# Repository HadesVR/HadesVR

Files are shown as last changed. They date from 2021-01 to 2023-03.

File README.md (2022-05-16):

EN
ES

name

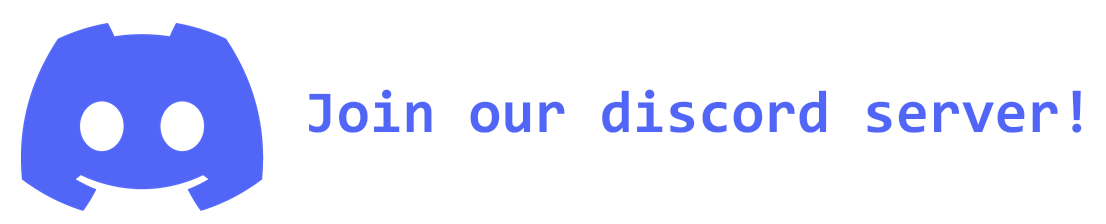
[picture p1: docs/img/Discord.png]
Discord (https://discord.gg/h2SFGEbuRH)

I made a discord server for support and whatever so [feel free to join.](https://discord.gg/h2SFGEbuRH)

# HadesVR       
HadesVR is a SteamVR compatible VR setup made for tinkerers. 

The setup includes DIY controllers that are capable of emulating HTC vive wands or most aspects of the Valve Index Knuckles controllers (including finger tracking!). It also includes tracking electronics for a Headset, including an integrated wireless receiver to receive the controllers' data.

There's also custom controller hardware like 3d printable shells (still a bit of a WIP) with their respective custom PCBs to build your own Knuckles controllers.

The SteamVR driver used to be based off of [TrueOpenVR](https://github.com/TrueOpenVR) but it's modified so heavily I'm making it it's own thing.
This driver also uses [PSMoveServiceEX](https://github.com/Timocop/PSMoveServiceEx) (for now at least) for the positional tracking of HMD and controllers, using ping pong balls and different colours of LED's.

For more information on *everything*, check out the [docs](docs/DocsIndex.md)!

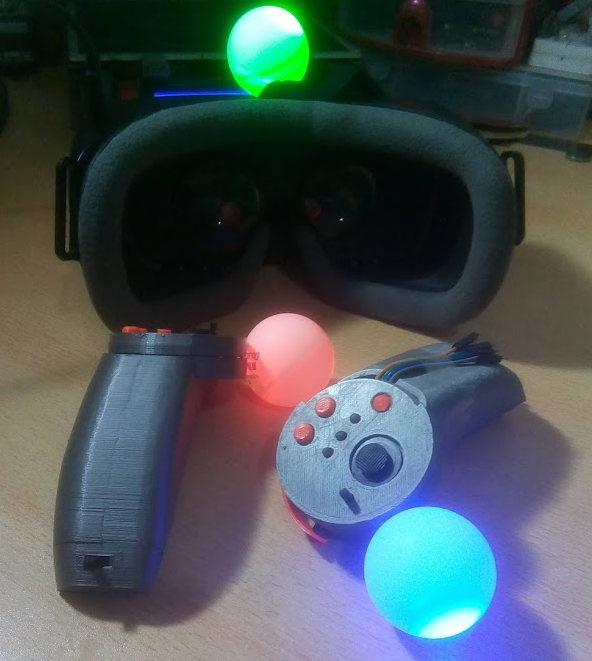
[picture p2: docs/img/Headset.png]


# How does it work and what can it do?

The headset connects to the PC and receives rotation and button data from both controllers through RF, while the tracking is done outside-in (base stations) using Playstation Move Cameras and [PSMoveService](https://github.com/psmoveservice/PSMoveService).

You can use the setup in: 
* Headset and controllers mode: The headset receives data from the controlers and mixed with the PSMoveService position tracking you get full 6dof tracking.
* Headset only mode: where you only have your HadesVR headset and the 6dof tracking (or 3dof if you don't use PSMoveService)
* Controller only mode: where if you already have a headset, you can use only the controllers part of the setup (you'll need to build an [RF receiver](docs/RFReceiver.md) to replace the HadesVR headset's built in one).

## What it can and cannot do:
* This driver can emulate Wand and Index controllers.
* This setup cannot do Inside out tracking.
* This driver cannot do Full body tracking ~~**yet**~~.
* Yes this thing plays beatsaber though I'm not sure how viable it is for expert+ diff since I suck at it.

# Custom hardware

As of right now the custom hardware available is:

### ⚠️Both the Basic HMD and Wand Controllers are missing the 3d printable parts right now. 
* [HadesVR Basic HMD PCB](https://github.com/HadesVR/Basic-HMD-PCB) 
* [HadesVR Wand Controllers](https://github.com/HadesVR/Wand-Controller)

### ⚠️Important disclaimer: I **very** very heavily discourage against building the knuckles controller, it's got a whole lot of problems right now that I haven't gotten around to fixing yet, there's problems with the boards and there's problems with the 3d printer models, and there's problems with the reliability of the capacitive sensors of each finger. The index controller is not an easy build: it relies on a lot of SMD components, stuff has to be assambled in order or else you won't be able to flash the bootloader and the 3d printable parts are all a bit crappy and hard to fit together properly. 

### Also there is a bit of an issue with the boards right now which makes it hard to flash the bootloader since AVR's require a crystal to do that for some dumb reason, so I heavily recommend against making the custom Index controllers for now.

#### I'm also working on an easier to build type of controllers that emulate the vive wands, made only out of through hole components though it's not ready yet (mainly missing the 3d printable shell at the moment). With that being said:

Or maybe you want to DIY your own controllers? check out the [Controllers docs](docs/DocsIndex.md#controllers) for building the controllers with regular Arduino boards!

# Demos

I've recorded a few demos of my HadesVR setup working in different games, these are all available in this [Youtube Playlist](https://www.youtube.com/playlist?list=PLPNX9YMrhQR2g2nwp1AN23K4V-8d-4bBV)

# Trello
I used to have a crappy little TODO list here but I'm gonna try to use [trello for HadesVR work](https://trello.com/b/4Ogw6SMk/hadesvr-stuff)

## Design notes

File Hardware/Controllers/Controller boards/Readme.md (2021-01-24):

# Controller boards

You can get the board files and stuff over [Here][BoardLink]

If you're using the custom controller boards, you'll have something that looks like this in your hands

Boards

You'll have to snap them off so you're left with two pairs of controller boards and a blank pcb square.

[BoardLink]: <https://oshwlab.com/liquidcgs/vrcontrollers_public>

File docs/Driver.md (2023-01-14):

# Driver

# Driver Installation
Driver installation is quite simple, the steps are as follows:
* Download the latest release of the driver from the [Releases Page](https://github.com/HadesVR/HadesVR/releases)
* Unzip the driver into your Steam\steamapps\common\SteamVR\drivers folder.
* Configure the driver

Assuming you have already followed the steps in the [Tracking](Tracking.md) doc, you should have PSMoveService already installed in your PC.

If you don't plan on making a 6dof headset (a 3dof headset for Sim racing, etc), you can skip the PSMoveService related steps.

# Driver Configuration

Driver configuration is pretty self explanatory, the driver configuration file is stored in hadesvr\resources\settings\default.vrsettings. To change the settings just open the file with the text editor of your liking.

If you're planning to use different drivers at the same time (HadesVR controllers with TOVR HMD for example), you'll also need to enable the `activateMultipleDrivers` setting in the Steam\config\steamvr.vrsettings file. 

The driver configuration is divided into a couple sections for tidyness, these are the following:

### "Driver" section where you'll find:
|Parameter|Type |Description|
| ---  | --- |--- |
| TransportMode | string | Either HID or UART depending on how HMD is connected, see below. |
| PSMSTrackerFrequency | int | The maximum update rate you have set on your psmoveservice trackers.|
| EnableDirectMode | bool | Enable direct mode? (Experimental, sort of broken. default value is 'false'.|
| EDID_VID | int | EDID VID for direct mode.|
| EDID_PID | int | EDID PID for direct mode.|

If `TransportMode` is set to `HID` (or left unset):

|Parameter|Type |Description|
| ---  | --- |--- |
| HID_VID | int | The VID value of your HID device, in decimal numbers. |
| HID_PID | int | The PID value of your HID device, in decimal numbers. |

If `TransportMode` is set to `UART`:

|Parameter|Type |Description|
| ---  | --- |--- |
| UART_Port | string | UART port name HMD is connected to, e.g. COM3. |
| UART_Baudrate | int | Baudrate used for UART communication, e.g. 115200 or 230400. |

### "Display" section where you'll find:
|Parameter|Type |Description|
| ---  | --- |--- |
| Stereo  | bool | Enables or disables Stereo display mode, keep enabled unless you're a cyclops. |
| IsDisplayOnDesktop  | bool | This makes it so a warning telling you your display isn't in fullscreen mode pops up when your window focus isn't on the VR viewport. |
| IsDisplayReal  | bool | ------ |
| IsSinglePanel  | bool | Set to true if using a single panel display. |
| IPD  | float | IPD setting, in meters. |
| FOV  | float | FOV setting, in degrees. |
| windowWidth  | int | Resolution Width of your VR screen |
| windowHeight  | int | Resolution Height of your VR screen |
| renderWidth  | int | The width (per eye) of the desired render resolution. |
| renderHeight  | int |The height (per eye) of the desired render resolution. |
| displayFrequency  | float | Here goes the refresh rate of your display. |
| windowX  | int | Here goes the Width resolution of your main screen. |
| windowY  | int | Don't touch this one. |
| ScreenOffsetX  | int | Viewport X offset. |
| ScreenOffsetY  | int | Viewport Y offset. |
| ViewportZoom  | float | Viewport Zoom, lower means higher zoom. |
| DistanceBetweenLenses  | float | This is the physical distance between the two lenses, in meters |
| DistanceBetweenViews  | float | Distance between views, in meters. This should be set as same as IPD in single panel mode and 0 in dual panel mode. |
| DisplayWidth  | float | Physical width of the display, in meters |
| DisplayCantAngle  | float | Cant angle in degrees of the displays (Experimental, slightly broken, things don't render properly at the edges of the views). |
| secondsFromVsyncToPhotons  | float | ------ |

### "Distortion" section where you'll find:
|Parameter|Type |Description|
| ---  | --- |--- |
| Red_K1,K2,K3  | float | Red distortion coefficients |
| Green_K1,K2,K3  | float | Green distortion coefficients|
| Blue_K1,K2,K3 |float| Blue distortion coefficients |

### "HMD" section where you'll find:
|Parameter|Type |Description|
| ---  | --- |--- |
| serialNumber  | string | The serial number of the HMD |
| modelNumber  | string | The model of the HMD |
| EnableHMD  | bool | Enables or disables the HMD part of the driver |
| MinFilterBeta | float | Minimum filter beta of the rotation filter |
| MaxFilterBeta | float | Maximum filter beta of the rotation filter |
| UseAccelerometers | bool | Enables the use of the IMU's accelerometer for position smoothing |
| Camera_Kalman_Measurement_Uncertainty | float | Camera measurement uncertainty of the Kalman position filter |
| Camera_Kalman_Estimation_Uncertainty | float | Camera estimation uncertainty of the Kalman position filter |
| Camera_Kalman_Process_Noise | float | Camera process noise of the Kalman position filter |
| IMU_Kalman_Measurement_Uncertainty | float | IMU measurement uncertainty of the Kalman position filter |
| IMU_Kalman_Estimation_Uncertainty | float | IMU estimation uncertainty of the Kalman position filter |
| IMU_Kalman_Process_Noise | float | IMU process noise of the Kalman position filter |
|HMDYawOffset|float| Yaw offset of the HMD in degrees|
|HMDPitchOffset|float| Pitch offset of the HMD in degrees|
|HMDRollOffset|float| Roll offset of the HMD in degres|
|HMDXOffset|float| X offset of the HMD in meters|
|HMDYOffset|float| Y offset of the HMD in meters|
|HMDZOffset|float| Z offset of the HMD in meters|

### "Controllers" section where you'll find:
|Parameter|Type |Description|
| ---  | --- |--- |
| EnableControllers  | bool | Variable to enable or disable controllers. |
| ControllerMode  | int | Sets the controller type, 0 being Knuckles controllers and 1 being wand controllers. |
| UseAccelerometers | bool | Enables the use of the IMU's accelerometer for position smoothing |
| Camera_Kalman_Measurement_Uncertainty | float | Camera measurement uncertainty of the Kalman position filter |
| Camera_Kalman_Estimation_Uncertainty | float | Camera estimation uncertainty of the Kalman position filter |
| Camera_Kalman_Process_Noise | float | Camera process noise of the Kalman position filter |
| IMU_Kalman_Measurement_Uncertainty | float | IMU measurement uncertainty of the Kalman position filter |
| IMU_Kalman_Estimation_Uncertainty | float | IMU estimation uncertainty of the Kalman position filter |
| IMU_Kalman_Process_Noise | float | IMU process noise of the Kalman position filter |
|CTRLRightYawOffset | float | Yaw offset of the Right controller in degrees|
|CTRLRightPitchOffset | float | Pitch offset of the Right controller in degrees|
|CTRLRightRollOffset | float | Roll offset of the Right controller in degrees|
|CTRLRightXOffset|float| X offset of the Right controller in meters|
|CTRLRightYOffset|float| Y offset of the Right controller in meters|
|CTRLRightZOffset|float| Z offset of the Right controller in meters|
|CTRLLeftYawOffset | float | Yaw offset of the Left controller in degrees|
|CTRLLeftPitchOffset | float | Pitch offset of the Left controller in degrees|
|CTRLLeftRollOffset | float | Roll offset of the Left controller in degrees|
|CTRLLeftXOffset|float| X offset of the Left controller in meters|
|CTRLLeftYOffset|float| Y offset of the Left controller in meters|
|CTRLLeftZOffset|float| Z offset of the Left controller in meters|

### "Trackers" section where you'll find:
|Parameter|Type |Description|
| ---  | --- |--- |
|EnableTrackers| bool| Enables or disables trackers (still work in progress, trackers do nothing as of right now.)
|TrackerMode| int | 0 meaning full body, 1 meaning waist tracking. |

### "Experimental" section where you'll find:
|Parameter|Type |Description|
| ---  | --- |--- |
|EnableDriftCorrection| bool| Enables or disables experimental drift correction
|LowerVelocityTreshold| float | The lower threshold of velocity in m/s in which the driver will attempt to correct for drift |
|UpperVelocityTreshold| float | The upper threshold of velocity in m/s in which the driver will attempt to correct for drift |
|Measurement_Uncertainty| float | Kalman filter measurement uncertainty for the smoothing filter used in drift correction. |
|Estimation_Uncertainty| float | Kalman filter estimation uncertainty for the smoothing filter used in drift correction. |
|HMD_Process_Noise| float | Kalman filter process noise for the smoothing filter used in drift correction on the HMD. 0 disables it |
|Controller_Process_Noise| float | Kalman filter process noise for the smoothing filter used in drift correction on the Controllers. 0 disables it |

# HID configuration
To configure the driver you will need the VID and PID values from the board you're using. The easiest way of getting them is going to the Arduino IDE, clicking on tools and clicking on get board info with the receiver plugged in:

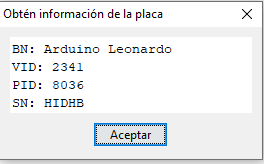
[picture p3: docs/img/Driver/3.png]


Do note these values are in HEX so to use them in the driver config file you'll need to convert them to decimal numbers.
to do that you can use websites like [Rapidtables](https://www.rapidtables.com/convert/number/hex-to-decimal.html), just input your VID and PID values one at a time and convert them to decimal numbers.

Once done, you'll get values like these and then all you have to do is load them up in your driver config file, the values you're looking to change are `HID_VID` and `HID_PID`, under the `Driver` section.



Make sure not to delete any commas, and not to get the VID and PID values backwards and proceed with the Display configuration.

# Display configuration

for your headset display to be recognized properly you must align it flat with the top right corner of your main display as seen in the following example:

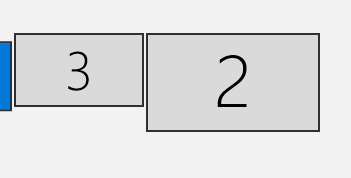
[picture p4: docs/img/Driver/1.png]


3 being your main display and 2 being your HMD's display. then you must input the Width of your main display (3 in this case) in pixels onto the `windowX` setting on the settings file but do not modify the windowY value of 0.

Then you've gotta set `windowWidth` and `windowHeight` to the respective width and height values of your vr screen, same goes for `renderWidth` and `renderHeight`. And last but not least: Set the `displayFrequency` to the one of your HMD's display.

If this doesn't work you might have messed up the alignment of the displays on the screen settings, remember the top line has to be flat like in the example picture.

you can also show the main vr output on your main screen for testing purposes by doing the following:
- Set `windowWidth` and `windowHeight` to the width and height of your main display
- Set the `renderWidth` and `renderHeight` to the width and height of your main display
- Set `windowX` to 0

# Usage and controller bindings

* Launch PSMoveService before opening SteamVR
* Launch SteamVR
* Close the "Running on monitor mode" notice
* Click on the Screen Viewport
* Calibrate controllers and headset by pressing F8 on your keyboard or the respective binding for it. (more on calibration below)

⚠️ if you just turned on your controllers/hmd it might drift for up to a minute, this is normal and you just need to keep it stil for a couple seconds until it settles.

## Initial calibration:
[TODO]
 
## Bindings:
### HMD only bindings:
Pressing F8 resets your yaw axis in case of IMU drift.

### Knuckles and Wand controllers:
Pressing Joystick click + trigger button on both controllers at the same time resets the yaw axis, make sure you're facing the correct way before doing so or else your controllers' axis will not match your headset axis.

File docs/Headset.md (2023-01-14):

# Headset
The headset will not only be in charge of showing you the image and relaying back rotation data from it's internal IMU, but it will also be in charge of receiving the RF Controller data and sending it back to the computer. Another thing that can be integrated into the headset is an USB Sound Card, that way it'll also have an integrated Microphone and a headphone jack for you to plug your headphones in. Though it's not mandatory.

I plan on eventually making a custom pcb for the headset that includes a 2 port USB hub, an audio interface for headphones and microphone integration, and maybe a couple other goodies like an attempt at backlight strobing to reduce screen blur.

# Hardware Needed

## Shell
For the shell you can use any "Phone VR" enclosure, they come in very different qualities but all of them should do the trick (even the carboard ones). Keep in mind the enclosure will dictate your max fov and that you can always modify the shell to allow for a wider fov.

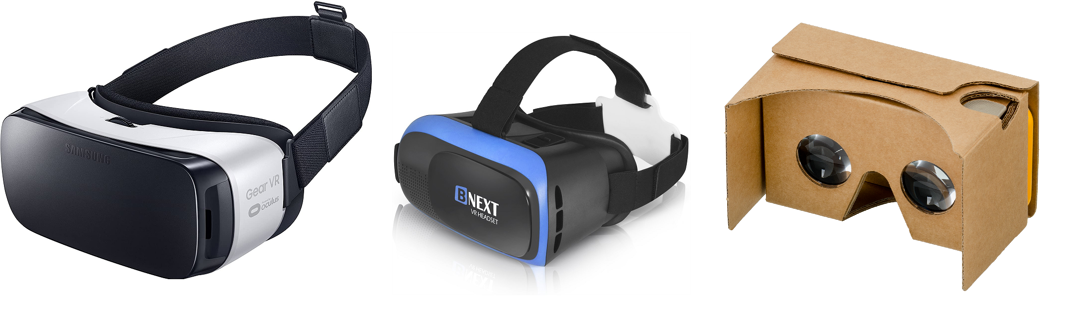
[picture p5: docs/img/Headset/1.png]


You could also 3d print the shell, like the guys over at [Relativty](https://github.com/relativty/Relativty#building-the-mechanical-parts) did. Keep in mind you'll also need to source your own lenses with the correct focal length and head strap.

⚠️ The screen mount depends on what screen you use and you'll have to design your own sice not all mounts fit all headsets/screen combinations.

## Electronics

As the main microcontroller I suggest sticking to stuff that supports the [Arduino HID library](https://www.arduino.cc/en/Reference/HID). That means:

* Arduino Leonardo
* Arduino Pro micro
* Arduino DUE (code might require some modification since it doesn't support EEPROM.)

An ideal candidate is the Arduino Pro Micro since it's based on the Atmega32u4 which is the microcontroller used on the Arduino Leonardo and it's fairly small.

Also needed are:
* An MPU9250 to gather rotation data (though you could use any IMU that's fast enough and can output rotation data to quaternions if you modify the code a bit to allow for that).

* An NRF24L01 to receive the controller data from both controllers*

* A 5v to 3.3v voltage regulator to power the NRF24 module*

* A High brightness LED that's a different colour from the ones used on the controllers (I suggest green) and a resistor for that LED for blob tracking (also needed is a white ping pong ball to put the LED into)**

    *: Only needed if you're also building the controllers.
    **: Only needed for 6dof tracking.

## Display(s)

There's a couple different displays you can use for this headset, anything from 4.5 to 6 inches should work just fine.
*As of right now*, using a phone with ALVR or RiftCat or whatever isn't supported though.

You can find these screens on Aliexpress, but make sure what you're getting is what you think you're getting. Ask the seller if the screen **AND** the driver board support the resolution and refresh rate they advertise.

Most of these screens come with a Blue driver board based around the [Toshiba TC358870XBG](https://toshiba.semicon-storage.com/ap-en/semiconductor/product/interface-bridge-ics-for-mobile-peripheral-devices/hdmir-interface-bridge-ics/detail.TC358870XBG.html), be skeptical of these boards since they support a huge multitude of displays at different refresh rates and resolutions, some sellers even claim they can drive two displays at 90hz.

There's a couple different versions of these blue driver boards, the most common one based around the TOSHIBA chip, the other one based on a clone of said chip.

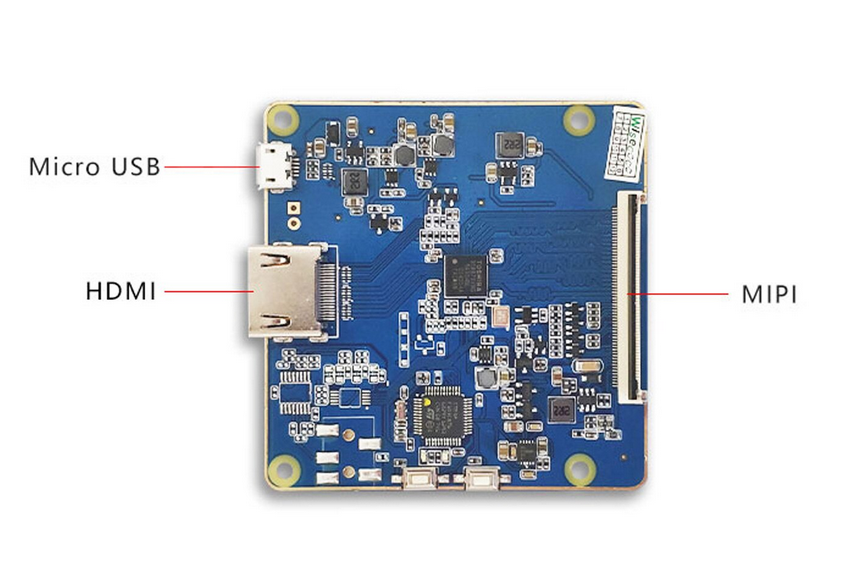
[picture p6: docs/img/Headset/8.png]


Some screen options are:

### LS055R1SX04 with Green board
With this option you'll have to purchase the [display](https://www.aliexpress.com/item/4000999801804.html) and [board](https://www.aliexpress.com/item/1005002330323719.html) separately. Make sure you choose the right display to go with the right board (LS055R1SX04 lcd won't work with LS055R1SX03 board) and make sure the display has a backlight before purchasing since these are usually used for resin 3d printers.

These screens are 1440x2560(vertical), they officially support up to 60Hz but with the board linked below they can be pushed to around 72hz without artifacts.

The board is meant to run the display at 60hz but it can easily do 72hz if you create a custom resolution in nvidia control panel or amd's driver settings thing.

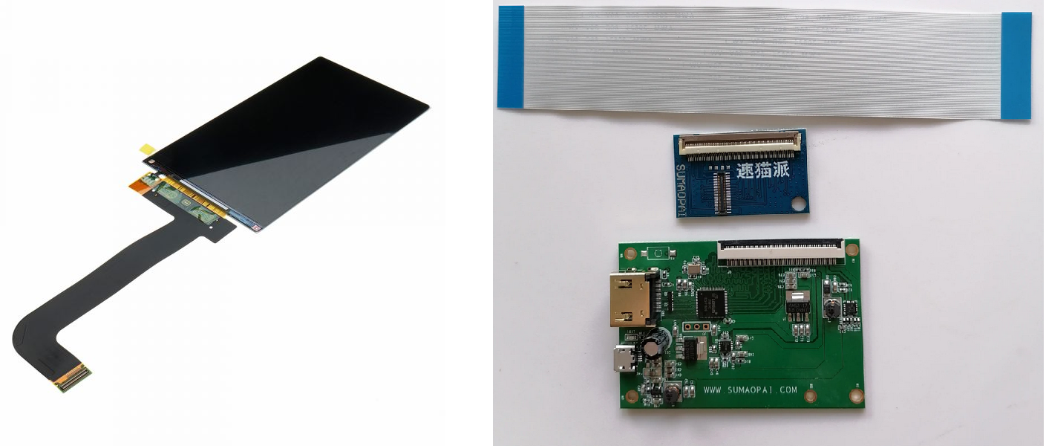
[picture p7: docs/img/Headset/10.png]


### LS055R1SX04 or LS055R1SX03 Blue board
These screens are 1440x2560(vertical), they officially support up to 60Hz but depending on the driver board they can be pushed to around 65hz without artifacts (this depends on the driver board).

⚠️ Make sure you're getting the correct refresh rate since a lot of sellers sell these boards with a driver board that's programmed to run at only 50hz

These are reasonably cheap since they're commonly used in resin 3d printers and can be found for around 50USD.

You can find these boards by searching with the terms "5.5 LCD MIPI"

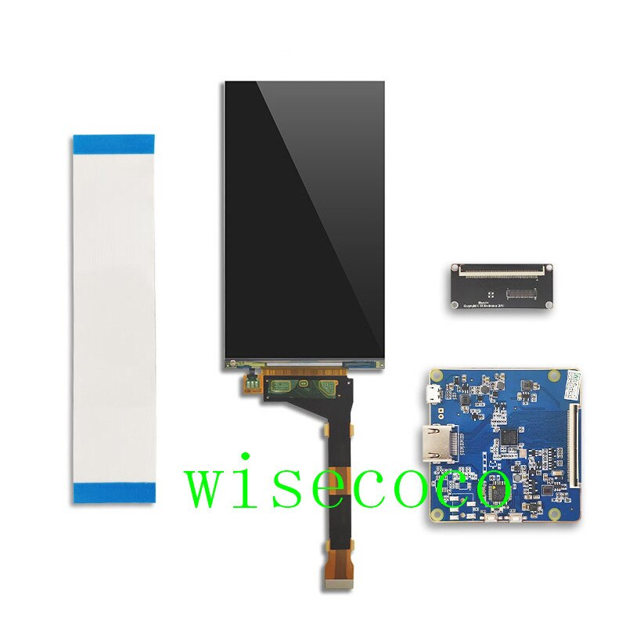
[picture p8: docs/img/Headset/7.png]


### Dual AMOLED H381DLN01
These screens are 1080x1200 per eye (2160x1200) and they claim to run at 90Hz.
They use the Blue driver board and the screens are 3.81 inches each and use AMOLED displays.

⚠️ Make sure you're getting the correct refresh rate before buying

⚠️ Make sure the driver splits the image into the two displays and doesn't just display the same image across both displays before buying.

These are a lot more expensive than the last one and can be found for around 170USD for the pair of screens + driver board
You can find these boards by searching with the terms "90Hz VR LCD"

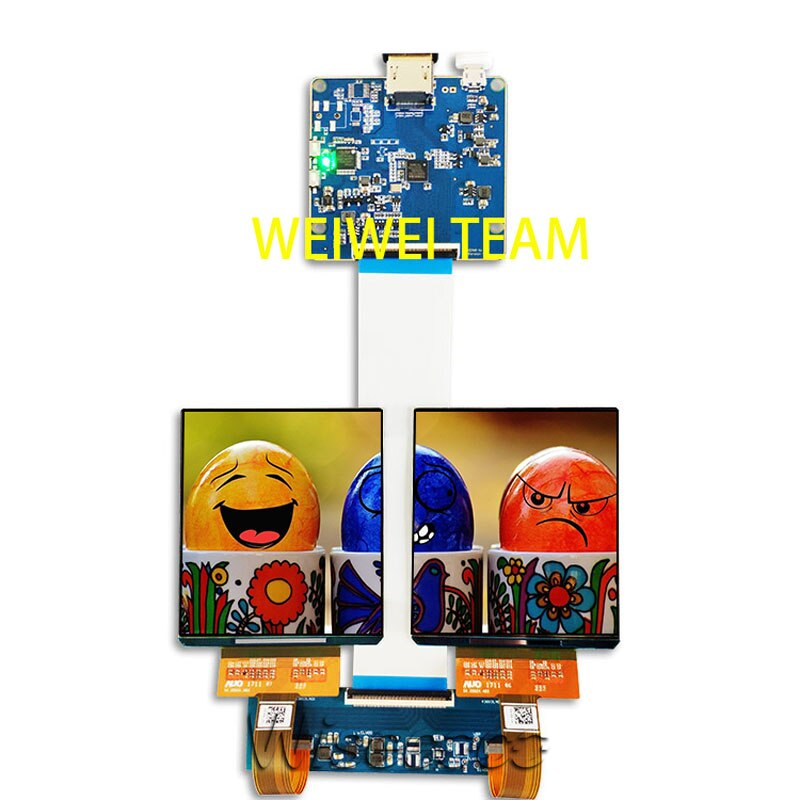
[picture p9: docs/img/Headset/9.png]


### Dual LS029B3SX02
These screens are 1440x1440 per eye (2880x1440) and run at 120hz.
The use a different driver board that uses DisplayPort as a video input and the displays are 2.9 inch IPS LCD.

⚠️ Make sure you're getting the correct refresh rate before buying

These go for around 180USD for the pair of screens and driver board, making them a better purchase than the dual AMOLED if you're looking for high refresh rate.

You can find these boards by searching with the terms "120Hz VR LCD"

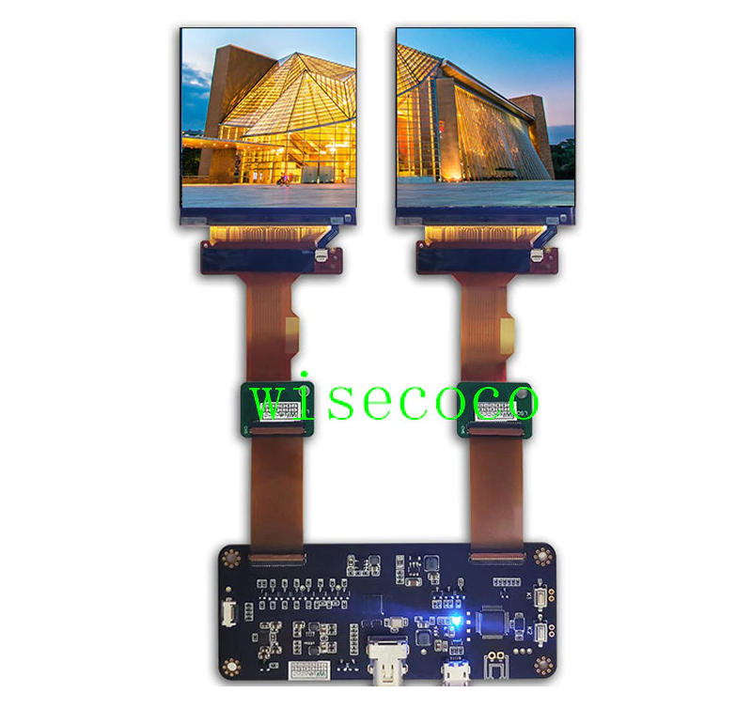
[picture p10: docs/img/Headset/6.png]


# Circuit schematic
Circuit pins for the Arduino pro micro are as follows:

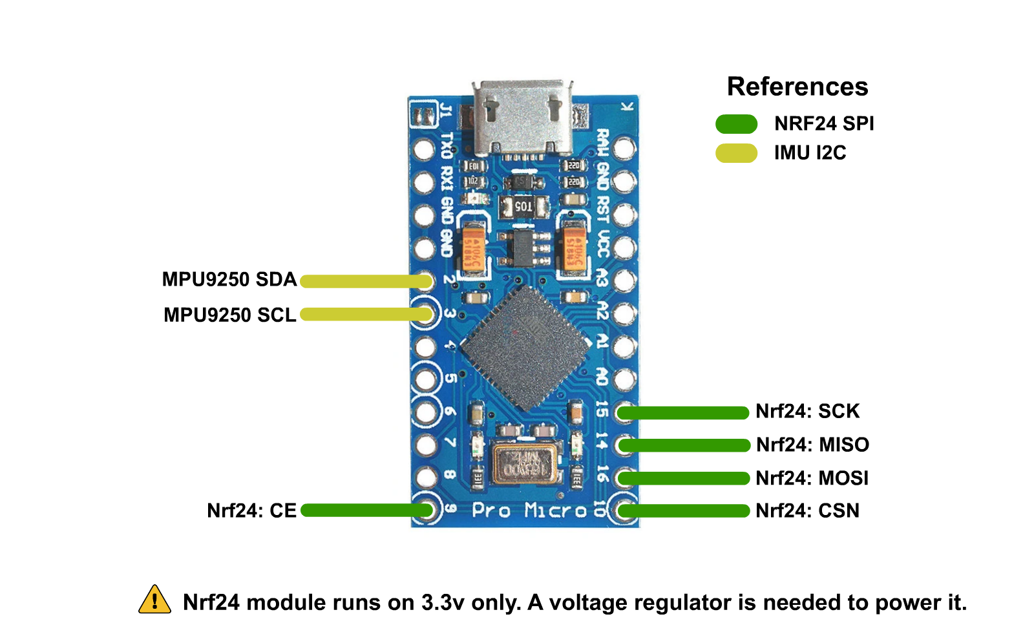
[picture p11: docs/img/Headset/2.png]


## ⚠️ IMPORTANT: YOU NEED A 5V TO 3.3V REGULATOR TO POWER THE NRF24 MODULE, ***THE PRO MICRO DOES NOT SUPPLY 3.3V ON ANY OF ITS PINS*** 
# Uploading the firmware

To upload the firmware you will need to have the [FastIMU](https://github.com/LiquidCGS/FastIMU) (also available on the Arduino library manager) and the [RF24 Arduino Library](https://github.com/nRF24/RF24) installed in your [Arduino IDE](https://www.arduino.cc/en/software). 

You can download the required library using the Libraries manager from within the Arduino IDE. The rest of the used libaries are already included in the firmware folder.

The steps to upload the firmware are as follows:

* Open Headset.ino inside the Software/Firmware/Headset folder
* Select "Arduino Leonardo" as the board if you're using an Arduino Pro Micro
* Select the correct COM port for the board
* Press the Upload button, if all goes well, you can move to setting the correct COMPort.

# Getting HID values

To configure the driver you will need the VID and PID values from the board you're using. The easiest way of getting them is going to the Arduino IDE, clicking on tools and clicking on get board info with the HMD plugged in:



Do note these values are in HEX so to use them in the driver config file you'll need to convert them to decimal numbers.
to do that you can use websites like [Rapidtables](https://www.rapidtables.com/convert/number/hex-to-decimal.html), just input your VID and PID values one at a time and convert them to decimal numbers.

Once done, you'll get values like these and then all you have to do is load them up in your driver config file. For more details on driver configuration, check out the [driver configuration docs](Driver.md#driver-configuration)



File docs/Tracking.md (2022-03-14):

# Tracking
The tracking of both controllers and the HMD is based on the same principle Playstation Move controllers are tracked. That is, by using different coloured blobs, and a camera (or multiple cameras) to know where in space each blob is located.

This type of tracking has the advantage of being reasonably cheap, since the blobs can be made out of ping pong balls and common LED's, and the cameras are standard Playstation Eye cameras.

## Why Playstation Eye cameras and not regular webcams?
- Playstation cameras can do up to 60fps at 640x480 which allows for smoother tracking.
- They are low cost and readily available.
- They have known lens distortion values. 
- All Playstation Eye cameras are created equal, which means a camera bought in the America and a camera bought in Europe will run exactly the same.

# What you'll need
- [Zadig](https://zadig.akeo.ie/)
- [PSMoveServiceEx](https://github.com/Timocop/PSMoveServiceEx)
- [PSMS Calibration mat](https://github.com/psmoveservice/PSMoveService/blob/master/misc/calibration/CalibrationMat.pdf), Ideally printed on letter paper, though A4 works fine too.
- *At least* 2 Playstation Eye cameras (**NOT** EYE TOY).
- USB extensions: you can extend up to 1.8m (6ft) (for a total of 3.6m (12ft)) with passive cables.

⚠️️ if you need more length you **will** have to use active cables.

## Why a *minimum* of 2 cameras and the amount I recommend.
A single camera results in jittery tracking since you can't do triangulation on a single camera and no redundancy, meaning that the second your tracking blob gets occluded (be it by your body or by something else) you'll lose all tracking.

Two cameras allow for triangulation and, *to some extent* redundancy. This is the bare minimum I'd recommend for vr.

The problem is that the moment one of your blobs gets occluded your tracking will turn into a jittery mess. *This is why I recommend three or four cameras.*

Three cameras not only allows for smoother, more accurate tracking, but it also allows for redundancy and since you only need two cameras for triangulation you can block the tracking blob for one camera entirely and still have decent tracking.

More cameras would allow for more redundancy, you can hook up as many as you want, but keep in mind USB bandwith limitations and processing power overhead. 

Maximum play area I'd say is about 4x4m (~13ft), any more and you'll have issues with your tracking due to the low video quality of these cameras. I'd keep the play area below 3.5x3.5m (~11x11ft).

# Installing the camera drivers

Download and install [Zadig](https://zadig.akeo.ie/), we'll be using Zadig to install our libusb camera drivers.

Plug in all your cameras and open up Device Manager, you'll probably see something similar to this:



To install the drivers open up Zadig, select one of the USB cameras, select libusb-win32 as your driver and click install driver.

⚠️ You should only install the driver on the "Interface 0" cameras

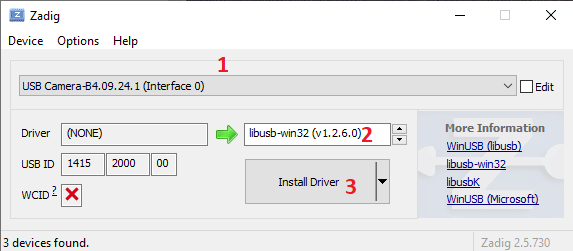
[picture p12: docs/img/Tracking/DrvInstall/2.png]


Once it is done installing, select the next camera and repeat the process untill you've installed the drivers for all cameras. If you've done everything correctly, your device manager should look something like this:



# Installing and configuring PSMSEx

Download and extract [PSMoveServiceEx](https://github.com/Timocop/PSMoveServiceEx/releases/tag/v0.12.6). and you should see something like this:

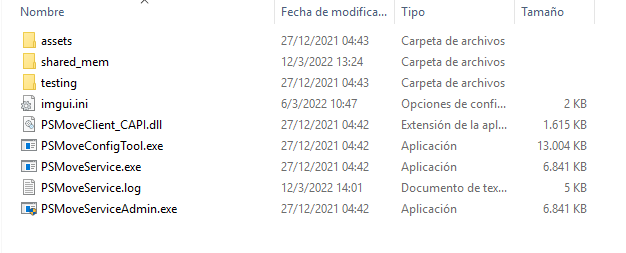
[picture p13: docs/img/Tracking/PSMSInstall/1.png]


Inside the "testing" folder you'll find a couple apps, the only one you'll be interested in here will be "test_camera_paralell.exe", You can open it to test all connected cameras if you have to.

Open PSMoveServiceAdmin.exe and let it run for a couple of seconds for it to create all the config files, after it's done, close it and press  "windows key + R", type in "%appdata%\PSMoveService" (without quotation marks) and press Enter.

You should now see something like this:

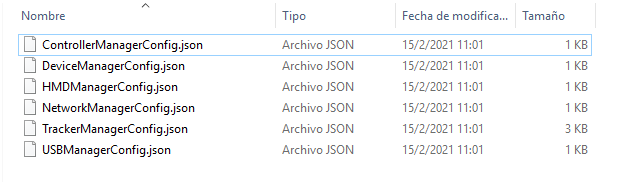
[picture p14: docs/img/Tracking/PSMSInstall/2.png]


* Open "ControllerManagerConfig.json" with notepad and change "virutal_controller_count" to 2, then save and exit
This allows you to calibrate and use PSMoveService without PSMove controllers by creating virtual controllers.

* Open "HMDManagerConfig.json" too and change "virtual_hmd_count" to 1, then save and exit.

After changing those files, run PSMoveServiceAdmin.exe once again for a couple of seconds and then exit.
This should have created a couple new files on your config folder, we're interested in these three in particular:



* Open each one and change "bulb_radius" to "2.0" in all of them
This is necessary because PSMove Controllers use a 4.5cm diameter tracking blob, while we use Ping Pong balls, which are 4cm in diameter.

Launch PSMoveServiceAdmin once again and then launch PSMoveConfigTool.exe and click connect. 

if you did everything correctly you should see this:

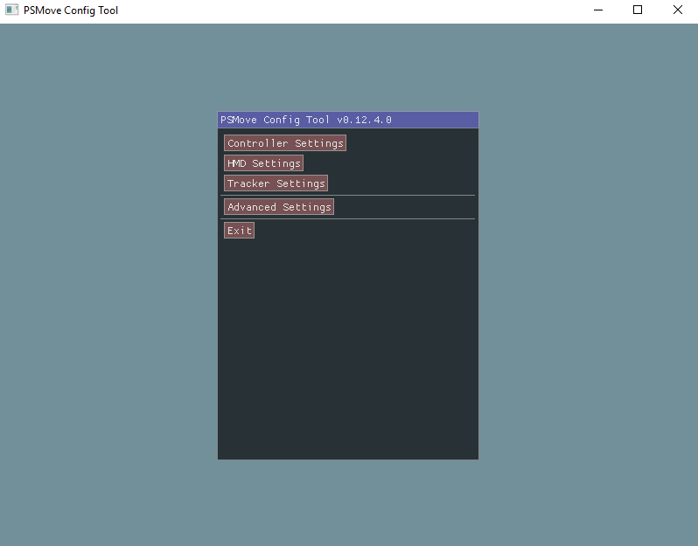
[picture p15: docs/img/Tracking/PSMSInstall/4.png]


After clicking Controller Settings you should see both of your virtual controllers. Select the correct tracking colour and hand for each (Controller 0 will be your Right hand controller and Controller 1 your left hand controller).

If you click on HMD Settings on the main menu you should also see your virtual HMD. Select the correct tracking colour here too.

You can also see if your Camera drivers are correctly installed by clicking on  "Tracker Settings" and checking to see if all your trackers (cameras) are in there.

Back to the main menu you'll also find a menu called "Advanced settings". Here you can change some of the advanced tracker settings, the defaults are good but you might want to set "Controller position smoothing" and "Controller position prediction" to 0.2 for smoother results. 
The other important setting under tracker manager config is the "Ignore pose from one tracker", which should always remain enabled. This prevents jittery 1 camera tracking.

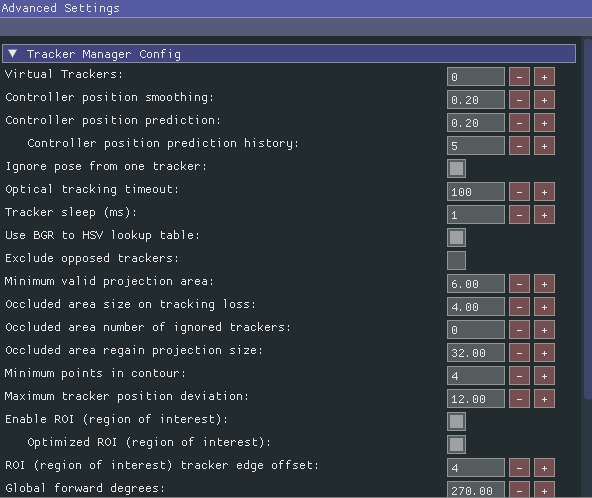
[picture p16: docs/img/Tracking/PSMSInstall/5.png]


# Room setup

There's different ways of setting up your trackers, these ways depend on the shape of your room and the amount of trackers you have.

The idea is to overlap the fields of view of the trackers as much as possible while also covering the most area possible.

The ideal setup for 2 and 3 cameras on a square room would be something like this:

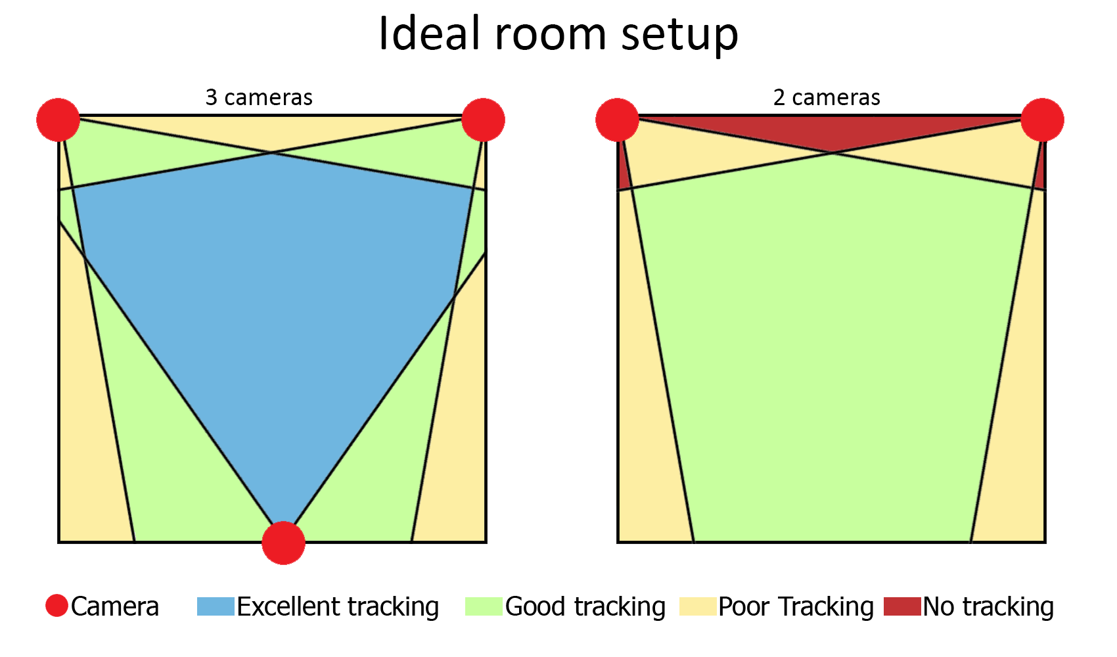
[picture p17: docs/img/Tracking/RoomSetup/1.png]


if you have 4 cameras each one would go in one corner of the room.

The more the cameras overlap, the more redundant your tracking will be.

Don't forget that your cameras should also cover the floor of your play area or you'll loose tracking if you crouch or try to reach for something on the floor!

Cameras should be mounted ~30cm above your head (1 foot) and angled down slightly in a way that they cover both the floor of your play area and the area above your head, that way you don't lose tracking whenever you try to reach for something on the floor, or whenever you try to reach for something above you.

To test what your cameras can see, make sure PSMoveService is closed and on the PSMoveService folder open "test_camera_paralell.exe", enter "n" and you should see the view of your different cameras.

### Important things on your room setup:

* ⚠️ Try to avoid bright sunlight while playing since this makes it harder for the cameras to see the tracking blobs reliably.

* ⚠️ Lighting should be easy to reproduce from the time you've done the color calibration, which means you should only light your area by a ceilling light and without much external light (sunlight, etc) to ensure that the blob colours look the same anywhere in the room, any time (night time, day time).

* ⚠️ Cover or turn off lights that are the same colour as your tracking blobs, these confuse the tracking *badly* and you'll see them during controller calibration (RGB Keyboards, etc).

# Controller calibration

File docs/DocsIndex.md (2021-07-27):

# Docs Index
Welcome to the docs Index, here you'll (hopefully) find everything you need to know about the Headset, the controllers and the driver. If there's something missing or you need help with something DM me on Discord at Liquid#4020 or email me at LiquidCGS@gmail.com.

These docs are still in a very early work-in-progress stage so don't expect everything to be here *yet*.

TODO: Hyperlink everything and create the docs etc.

## [Headset](Headset.md)

- [Hardware needed](Headset.md#hardware-needed)
    - [Shell](Headset.md#shell)
    - [Electronics](Headset.md#electronics)
    - [Display(s)](Headset.md#displays)
- [Circuit schematic](Headset.md#circuit-schematic)
- [Uploading the firmware and calibrating the magnetometer](Headset.md#uploading-the-firmware-and-calibrating-the-magnetometer)
- [Getting HID values](Headset.md#getting-hid-values)

## [RF Receiver](RFReceiver.md)

- [Hardware needed](RFReceiver.md#hardware-needed)
- [Circuit schematic](RFReceiver.md#circuit-schematic)
- [Uploading the firmware](RFReceiver.md#uploading-the-firmware)
- [Getting HID values](RFReceiver.md#getting-hid-values)

## [Controllers](Controllers.md)

- [Wand controller](Controllers.md#wand-controllers)
    - [Hardware needed](Controllers.md#hardware-needed-per-controller-is-as-follows)
    - [Controller Pinouts](Controllers.md#controller-pinouts-are-the-following)
- [Index Controller](Controllers.md#knuckles-controllers)
    - [Hardware needed](Controllers.md#hardware-needed-per-controller-is-as-follows-1)
    - [Controller Pinouts](Controllers.md#controller-pinouts-are-the-following-1)
- [Calibration](Controllers.md#calibration)

## Trackers
- Hardware needed
- Circuit schematic

## [Tracking](Tracking.md)

- [What you'll need](Tracking.md#what-youll-need)
- [Installing the camera drivers](Tracking.md#installing-the-camera-drivers)
- [Installing and configuring PSMoveService](Tracking.md#installing-and-configuring-psms)
- [Room Setup](Tracking.md#room-setup)
- [Controller calibration](Tracking.md#controller-calibration) (wip)

## [Driver](Driver.md)

- [Driver Installation](Driver.md#Driver-Installation)
- [Driver Configuration](Driver.md#Driver-Configuration)
- [HID Configuration](Driver.md#hid-configuration)
- [Display Configuration](Driver.md#Display-configuration)
- [Usage and controller bindings](Driver.md#Usage-and-controller-bindings)

## Troubleshooting

Driver troubleshooting:
- Error 422
- Red viewport
- Headset not connected

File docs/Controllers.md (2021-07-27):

# Controllers

This doc talks about designing your own DIY controllers, if you want to see the custom ones (with the custom pcbs and 3d printable parts) you should check out the [Custom Hardware]() list.

HadesVR supports two kinds of controllers as of right now: Wand-like controllers and Knuckles-like controllers with all of their supported inputs respectively.
Controllers connect through RF, directly to the Headset which then sends the received controller data over to the PC, both controllers require similar hardware with some minor differences:

# Wand Controllers:

These controllers aim to simulate the original Vive wand controllers, they're easier to build option to the Knuckles ones but they're lacking the finger tracking aspect.
These controllers support analog trigger though it's not enabled by default, to allow for it you just need to change a couple lines of code. They also have battery % monitoring but you need to calibrate that on your own and tends to not be super accurate.

## Hardware needed per controller is as follows:
| Component | Purpose | Notes | Amount |
| --- | --- | ----- | --- |
| Arduino Nano/UNO/Pro Mini* | The brains of the controller | keep in mind you'll need a serial programmer if you're using a Pro Mini | 1 |
| MPU9250* | Used to gather rotation data | Orientation of the IMU matters so keep that in mind. | 1 | 
| NRF24L01  | Used to transmit the controller data over to the HMD | You *will* need a 3.3v regulator if you're using a Pro Mini | 1 | 
| 5mm Red or Blue LED | Used for 6dof tracking | Each controller/headset has to have a different color: For example Green HMD, Red Left controller, Blue Right controller. | 1 |
| Tact switches | You'll be using these as your Trigger, grip, menu and system buttons | You can use Rubber dome switches, those are a lot more comfortable than the hard plastic ones. | 4 |
| Resistor for the LED | Used to limit the current for the tracking LED | It's value depends on the color of the LED and the voltage you're using. | 1 |
| Any lithium battery | Will power the controller so I recommend 18650s | avoid Ultrafire batteries at all cost they lie about their capacity. | 1 |
| TP4056 Battery charger with protection | Is in charge of charging and protecting your battery | Remember to set the charging current to 0.5c to be safe. | 1 |
| 5v step up converter | To power the Arduino | Needed unless you've got a 3.3v arduino, then you'll need a 3.3v ldo regulator like the HT7533 or MCP1700-3.3| 1 |
| ON-OFf Switch | To turn on or off the controllers | Goes between the output positive of the tp4056 board and the step up converter/regulator.| 1 |
| Analog stick module with button | Your main Analog stick | any will do really, if yours doesn't have a button you'll need an extra tact switch to simulate trackpad click. | 1 |
| White ping pong ball | Used to difuse the LED's light for 6dof tracking | Any will do as long as it's white and 40mm in diameter | 1 |

*can use any (preferrably) 9dof IMU but you'll need to modify the code a bit to allow for that.

## Controller pinouts are the following:

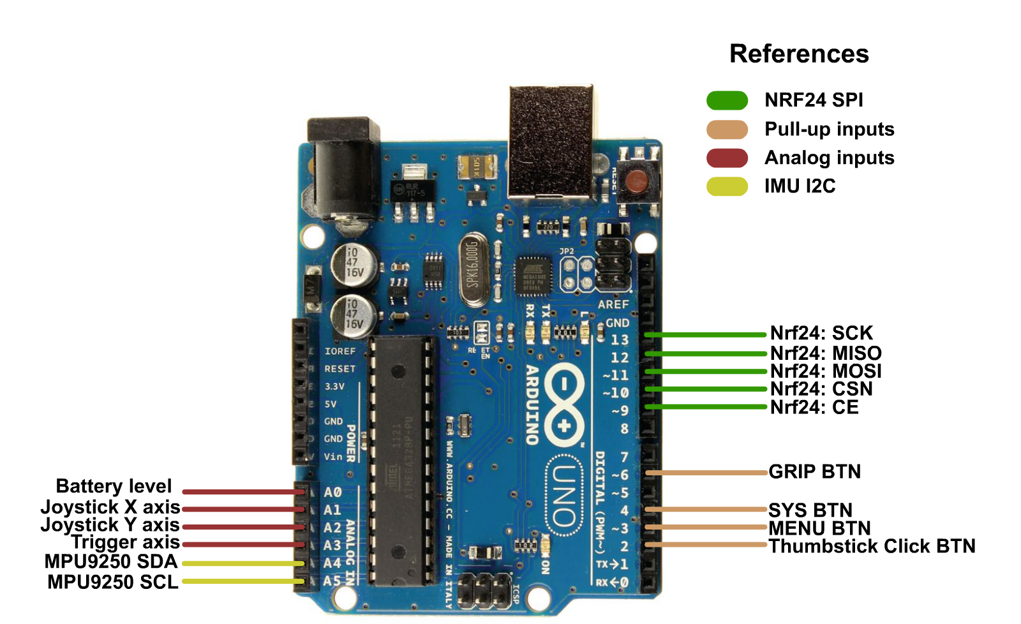
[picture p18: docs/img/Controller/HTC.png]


Battery level monitoring is done using a 1k-3.3k resistor divider if you're using a 3.3v arduino. If you're using a 5v arduino with a step up converter you can connect the battery + terminal directly to the A0 analog pin.
A0 can also be left floating if battery level monitoring is not desired.

Digital pins all have internal pull up resistors programmed so all you have to do is put the switch between the pin and GND.

# Knuckles Controllers

Made to simulate the Valve Index knuckles' controllers, with full support for finger tracking with a bit of a harder build.
These also support analog triggers though it is disabld by default.
Also supported is analog finger curl, also disabled by default since you'd need a microcontroller with 12 or more analog inputs to be able to detect the curl of each finger.

Hardware is mostly similar to the Wand controllers with the adition of 3 buttons to detect the status of the middle, ring and pinky finger. These buttons can be replaced by a TTP224 touch sensor for capacitive sensing of the fingers.

You might notice a lack of a grip button, it's not needed since we can get the grip status and strength from the middle,ring and pinky buttons: middle finger only: 50% grip strenth, middle and ring = 75% strength, middle ring and pinky: 100% strength.

## Hardware needed per controller is as follows:
| Component | Purpose | Notes | Amount |
| --- | --- | ----- | --- |
| Arduino Nano/UNO/Pro Mini* | The brains of the controller | keep in mind you'll need a serial programmer if you're using a Pro Mini | 1 |
| MPU9250* | Used to gather rotation data | Orientation of the IMU matters so keep that in mind. | 1 | 
| NRF24L01  | Used to transmit the controller data over to the HMD | You *will* need a 3.3v regulator if you're using a Pro Mini | 1 | 
| 5mm Red or Blue LED | Used for 6dof tracking | Each controller/headset has to have a different color: For example Green HMD, Red Left controller, Blue Right controller. | 1 |
| Tact switches | You'll be using these as your Trigger, system, A, B, Trackpad and finger sensing buttons | You can use Rubber dome switches, those are a lot more comfortable than the hard plastic ones. | 10 |
| Resistors for the trackpad resistor network | to convert the status of 3 switches into an analog value | 2x1k, 2x10k 1x3.3k | 5 |
| Resistor for the LED | Used to limit the current for the tracking LED | It's value depends on the color of the LED and the voltage you're using. | 1 |
| Any lithium battery | Will power the controller so I recommend 18650s | avoid Ultrafire batteries at all cost they lie about their capacity. | 1 |
| TP4056 Battery charger with protection | Is in charge of charging and protecting your battery | Remember to set the charging current to 0.5c to be safe. | 1 |
| 5v step up converter | To power the Arduino | Needed unless you've got a 3.3v arduino, then you'll need a 3.3v ldo regulator like the HT7533 or MCP1700-3.3| 1 |
| ON-OFf Switch | To turn on or off the controllers | Goes between the output positive of the tp4056 board and the step up converter/regulator.| 1 |
| Analog stick module with button | Your main Analog stick | any will do really, if yours doesn't have a button you'll need an extra tact switch to simulate trackpad click. | 1 |
| White ping pong ball | Used to difuse the LED's light for 6dof tracking | Any will do as long as it's white and 40mm in diameter | 1 |

*can use any (preferrably) 9dof IMU but you'll need to modify the code a bit to allow for that.

## Controller pinouts are the following:

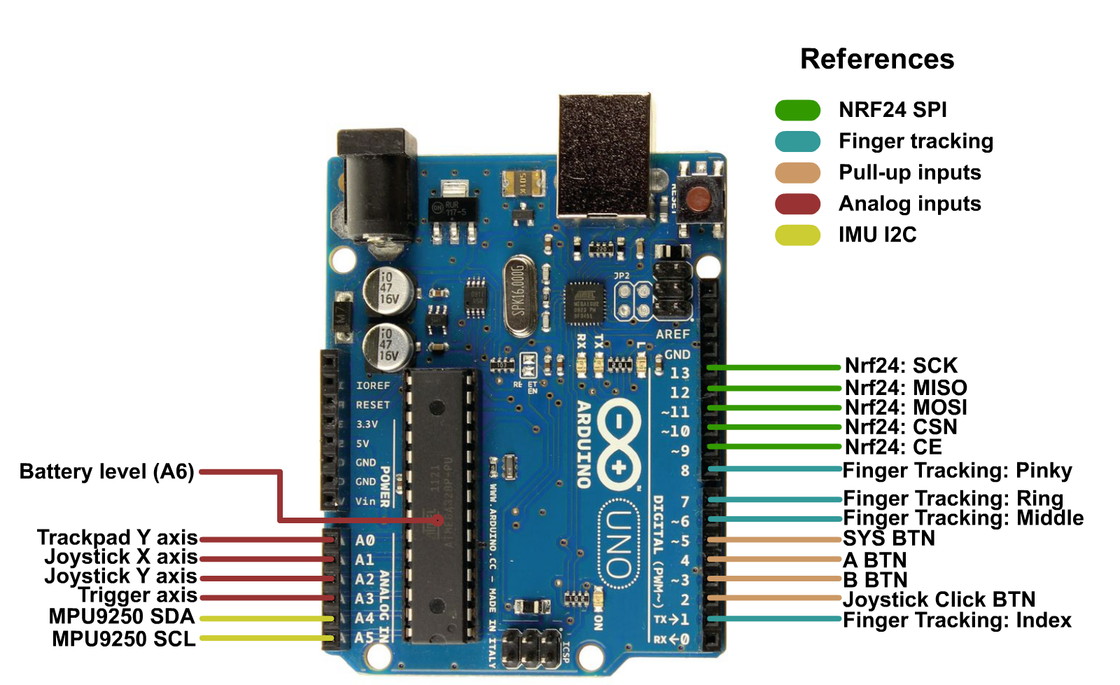
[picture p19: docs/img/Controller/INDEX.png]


Battery level monitoring is done using a 1k-3.3k resistor divider if you're using a 3.3v arduino. If you're using a 5v arduino with a step up converter you can connect the battery + terminal directly to the A0 analog pin.
A0 can also be left floating if battery level monitoring is not desired.

Digital pins all have internal pull up resistors programmed so all you have to do is put the switch between the pin and GND.

# Calibration
For all controllers you'll need to calibrate:
* The joystick maximums, minimums and deadzones
* The battery level
* The IMU's magnetometer
* In the case of the index controller the trackpad position.

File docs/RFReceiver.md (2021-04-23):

# RF Receiver

This is only needed if you already have an HMD and want to build only the controller part of the setup.

This RF receiver is in charge of receiving rotation and button data from the controllers, replacing the need for the HadesVR headset.

# Hardware Needed
I suggest sticking to stuff that supports the [Arduino HID library](https://www.arduino.cc/en/Reference/HID). An ideal candidate is the Arduino Pro Micro since it's based on the Atmega32u4 and it's fairly small.

Also needed are:
* An NRF24L01 to receive the controller data from both controllers
* A 5v to 3.3v voltage regulator to power the NRF24 module

# Circuit schematic
Circuit pins for the Arduino pro micro are as follows:

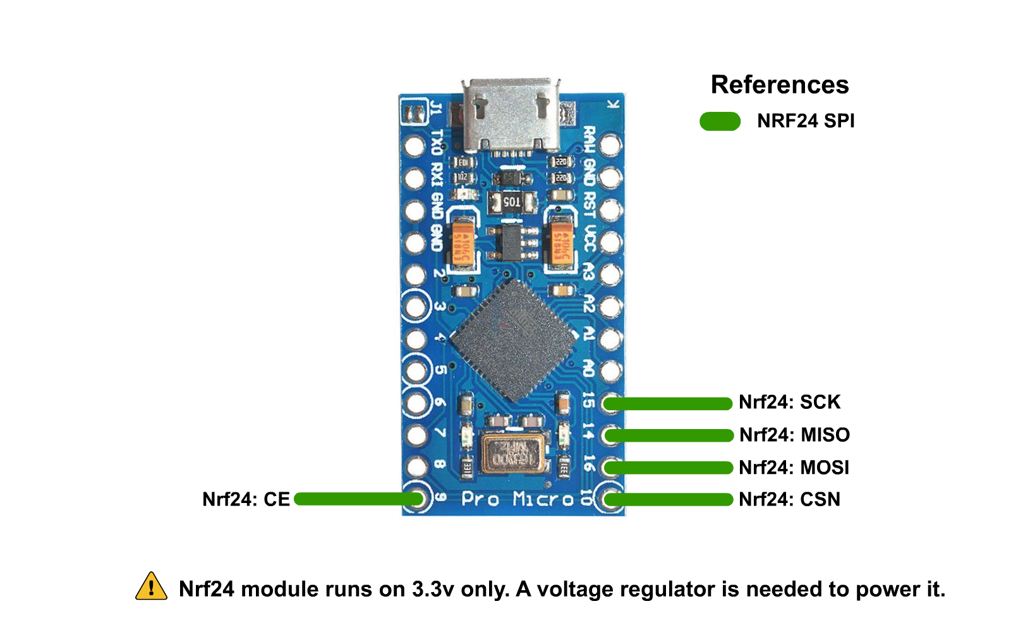
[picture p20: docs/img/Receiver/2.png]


## ⚠️ IMPORTANT: YOU NEED A 5V TO 3.3V REGULATOR TO POWER THE NRF24 MODULE, ***THE PRO MICRO DOES NOT SUPPLY 3.3V ON ANY OF ITS PINS*** 

# Uploading the firmware

To upload the firmware you will need to have the [RF24 Arduino Library](https://github.com/nRF24/RF24) installed in your [Arduino IDE](https://www.arduino.cc/en/software). 

You can download the required library using the Libraries manager from within the Arduino IDE. The rest of the used libaries are already included in the firmware folder.

The steps to upload the firmware are as follows:

* Open Receiver.ino inside the Software/Firmware/Receiver folder
* Select "Arduino Leonardo" as the board if you're using an Arduino Pro Micro
* Select the correct COM port for the board
* Press the Upload button, if all goes well, you can move to setting the correct COMPort.

# Getting HID values

To configure the driver you will need the VID and PID values from the board you're using. The easiest way of getting them is going to the Arduino IDE, clicking on tools and clicking on get board info with the receiver plugged in:



Do note these values are in HEX so to use them in the driver config file you'll need to convert them to decimal numbers.
to do that you can use websites like [Rapidtables](https://www.rapidtables.com/convert/number/hex-to-decimal.html), just input your VID and PID values one at a time and convert them to decimal numbers.

Once done, you'll get values like these and then all you have to do is load them up in your driver config file. For more details on driver configuration, check out the [driver configuration docs](Driver.md#driver-configuration)



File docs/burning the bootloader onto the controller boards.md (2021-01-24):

 
 If you're using the custom boards you'll need to flash a custom bootloader that lets you use the internal 8Mhz oscillator as a clock signal. I recommend using [MiniCore][MiniCore], instructions on how to add it to your arduino IDE are right [here][installMiniCore].

# Bootloader minimum component requirement
After soldering these components you'll be ready to flash the bootloader:
| Left Board | Right Board |Value|
| --- | --- |---|
|U3|U9|Atmega328p
|R12|R11|10kΩ
|U10|U4|3.3v LDO
|C19|C12|1uF
|C20|C13|1uF

 - Reminder: you can get the LDO regulator off of your MPU9250 since we're not going to be using it anyways.

# Bootloader Installation

The easiest way to flash the bootloader is using an Arduino as ISP. Connect the board like shown in the picture:

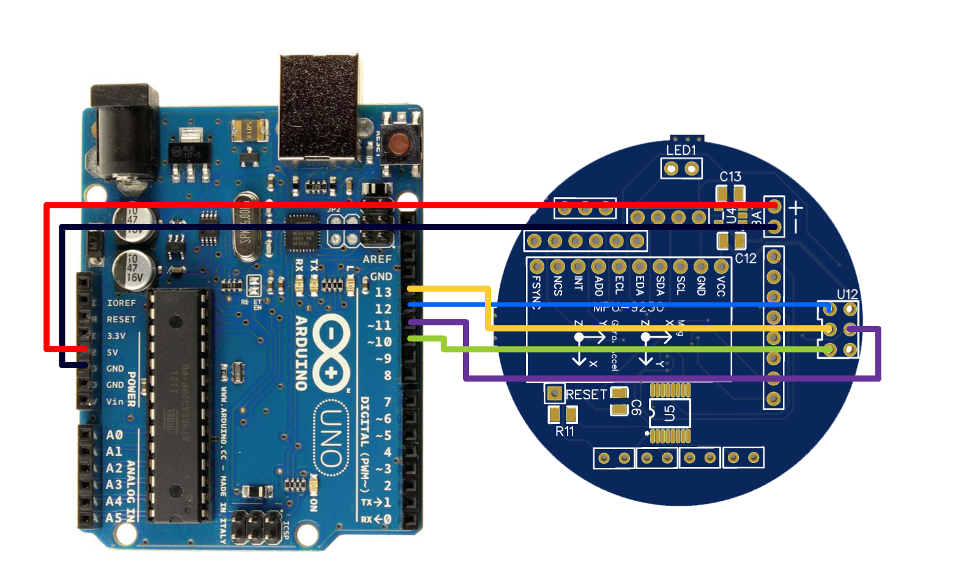
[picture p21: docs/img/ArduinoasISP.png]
ArduinoAsISP


Upload the Arduino as ISP sketch to the Arduino, under the tools menu, click boards, select Minicore and then use the following settings:

| Setting | Value |
| --- | --- |
|Board|Atmega328|
|Clock|Internal 8Mhz|
|BOD|2.7V|
|EEPROM|EEPROM Retained|
|LTO|LTO Disabled|
|Variant|328P/328PA|
|Bootloader|Yes(UART0)|

After selecting these settings, under tools, select "Burn Bootloader" the Led's on your arduino should flash a couple times and if all goes well you should see the message "done burning bootloader" at the bottom of the IDE.

After burning the bootloader you can upload the firmware either using the current setup with the Arduino as ISP, or you can hook up an FTDI programmer to the debug port and the reset line and program it through serial.

Pinouts

   [MiniCore]: <https://github.com/MCUdude/MiniCore>
   [installMiniCore]: <https://github.com/MCUdude/MiniCore#how-to-install>

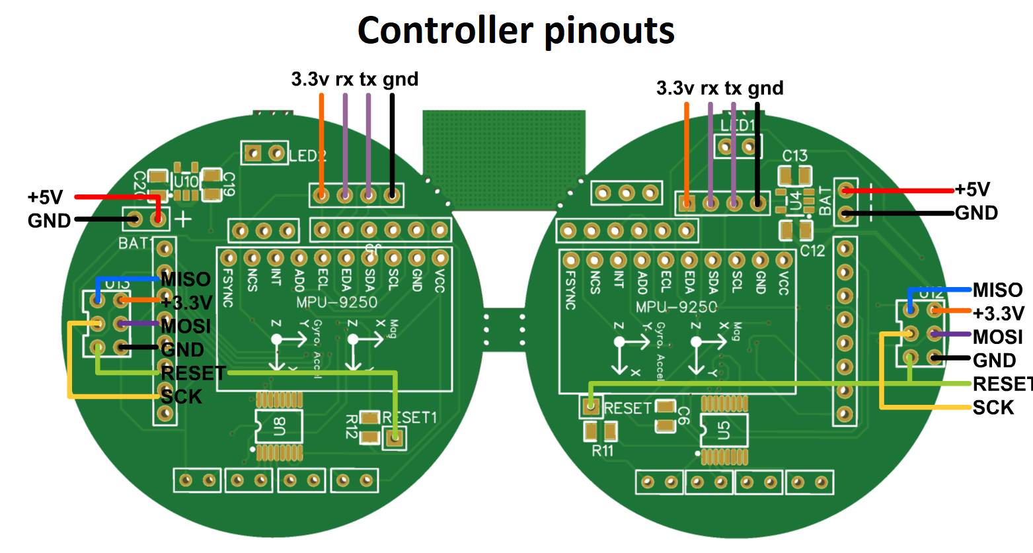
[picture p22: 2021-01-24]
Hardware/Controllers/Controller boards/Pinouts.png

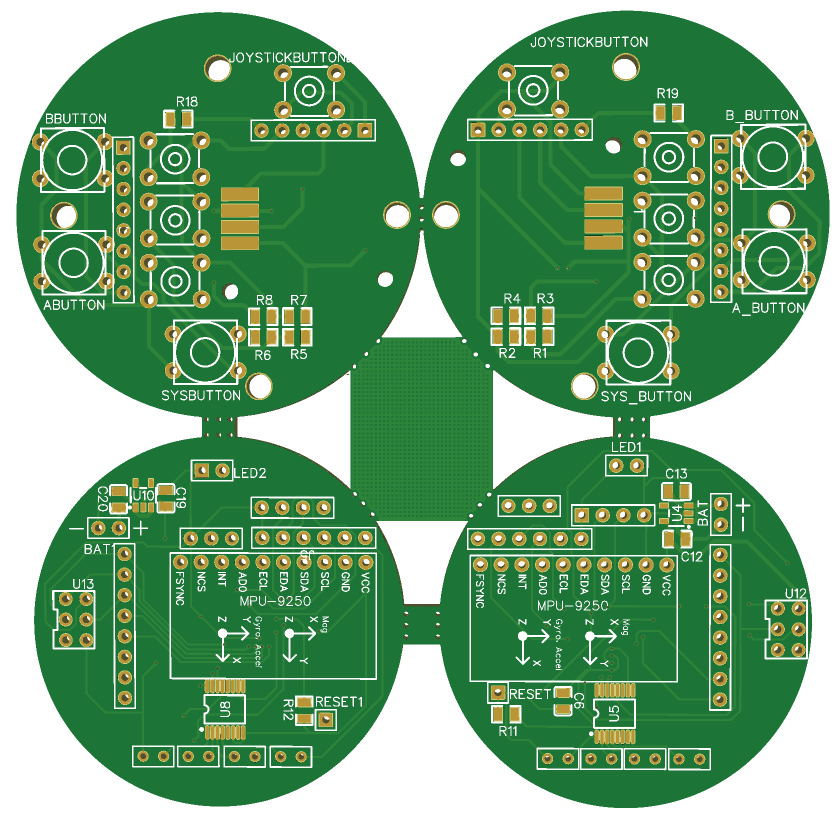
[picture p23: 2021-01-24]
docs/img/Boards.png

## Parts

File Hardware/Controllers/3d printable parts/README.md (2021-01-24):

# 3D printable parts notes:

  - All parts print without any support material
  - 0.1mm layers recommended
  - You **might** need to enlarge the SYS button hole slightly
  - You'll need to carefully glue the TP4056 in place without getting glue in the usb connector
  - *The 3d printed clips **will most likely snap***, this will get fixed soon™, In the meantime superglue will do

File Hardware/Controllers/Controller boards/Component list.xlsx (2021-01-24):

Component | Value | Package | Amount | Notes | Image
C12,C13,C19,C20,C26,C27 | 1uF | C0805 | 6 |  | https://i.imgur.com/zF4PCJ5.jpg
C5,C6,C7,C8 | 100nF | C0805 | 4 |  | https://i.imgur.com/zF4PCJ5.jpg
C1,C2,C3,C4,C9,C14,C15,C16 | 22-47pF | C0805 | 8 |  | https://i.imgur.com/zF4PCJ5.jpg
R4,R5,R9,R14,R18,R19 | 1k | R0805 | 6 |  | https://i.imgur.com/az6icQZ.jpg
R3,R6,R10,R13 | 3,3k | R0805 | 4 |  | https://i.imgur.com/az6icQZ.jpg
R1,R2,R7,R8,R11,R12 | 10k | R0805 | 6 |  | https://i.imgur.com/az6icQZ.jpg
U3,U9 | Atmega328p | TQFP-32 | 2 |  | https://i.imgur.com/sBEZ3Ss.jpg
U5,U8 | TTP224 | SSOP-16 | 2 | You can desolder these from the 4 channel touch modules if you're brave. | https://i.imgur.com/BNVEFjw.jpg
U4,U10 | 3.3v LDO(100ma) | SOT-23 | 2 | You can get this LDO from the IMU board if you're using an MPU9250. | https://i.imgur.com/xfNOqTF.jpg
U1,U2 | NRF24L01 MINI |  | 2 | it's important you use the MINI variant, the standard board is too large. | https://i.imgur.com/hnsKUj2.jpg
S1,S2 | MPU9250 | MPU9250 | 2 | you can harvest the LDO from these, don't forget to bridge the solder jumper onboard if you do | https://i.imgur.com/1zmey4m.jpg
A,b,Sys buttons | x88HS soft touch | 8*8*5 tact sw | 6 | Rubber tact switches(any will do), you can replace them with regular ones but I don't recommend it. | https://i.imgur.com/S2G7Ujb.jpg
Trackpad, trigger and joystick click buttons | Tact switch | 6*6*12 | 10 | You'll want to get the longer, 12mm ones and then file them down if needed | https://i.imgur.com/uYtKGHz.jpg
PSP1000 JOYSTICKS |  |  | 2 | Really cheap joysticks, they do the job pretty wel | https://i.imgur.com/Pe1h1S3.jpg
Stuff needed for the rest of the controllers:
Ping pong balls | White ones |  | 2
High brightness Red LED | LED | LED | 1
High brightness Blue LED | LED | LED | 1
Resistors for the LEDS |  |  | 2 | These values will depend on the vf of your LEDs, I used 82ohm and 22ohm for Red and blue respectively
TP4056 with dw01 protection | module |  | 2 |  | https://i.imgur.com/VV4NblW.png
18650 battery | 2000mAh+ | 18650 | 2 | any will do but if you want long playtime you'll want original cells, LG or Samsung ones are great!
cables (26-28awg or so)
Sliding switch |  |  | 2 | see pic | https://i.imgur.com/8G0NWzS.jpg

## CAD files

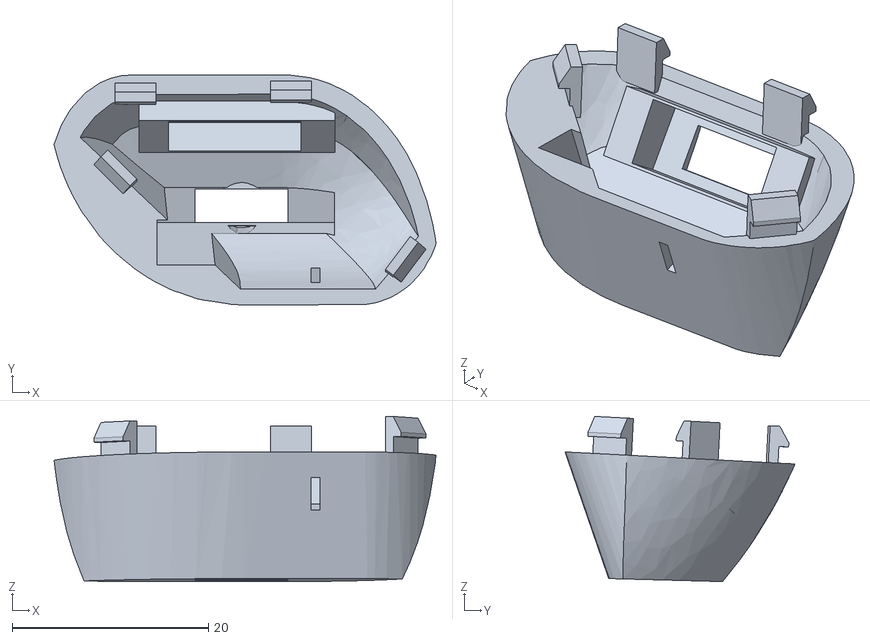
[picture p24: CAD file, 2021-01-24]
Hardware/Controllers/3d printable parts/Left Controller/bottompart.stl
38.9 x 23.5 x 16.8

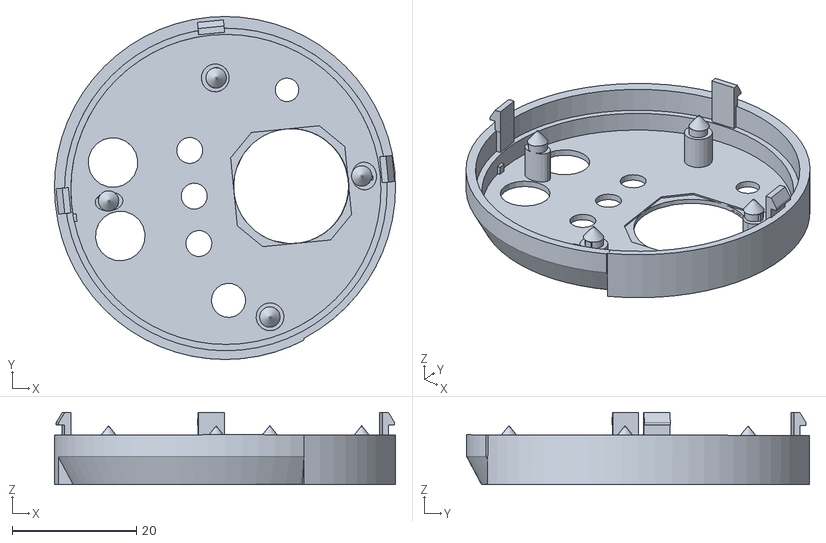
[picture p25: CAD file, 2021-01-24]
Hardware/Controllers/3d printable parts/Right Controller/toppart.stl
55.0 x 55.3 x 11.7

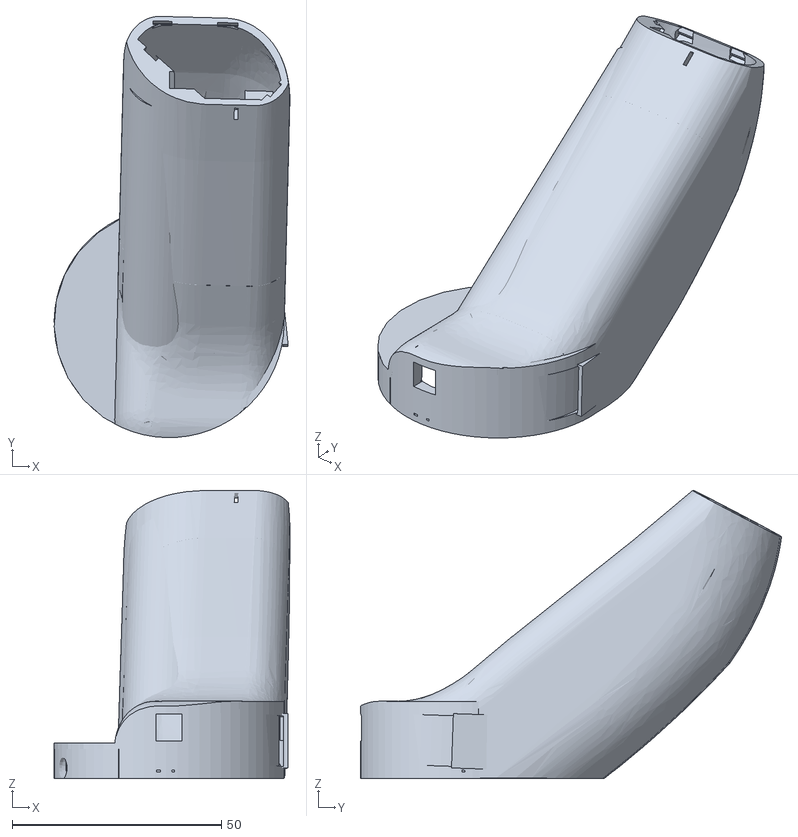
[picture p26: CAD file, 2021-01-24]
Hardware/Controllers/3d printable parts/Right Controller/middlepart.stl
56.4 x 100.7 x 68.9

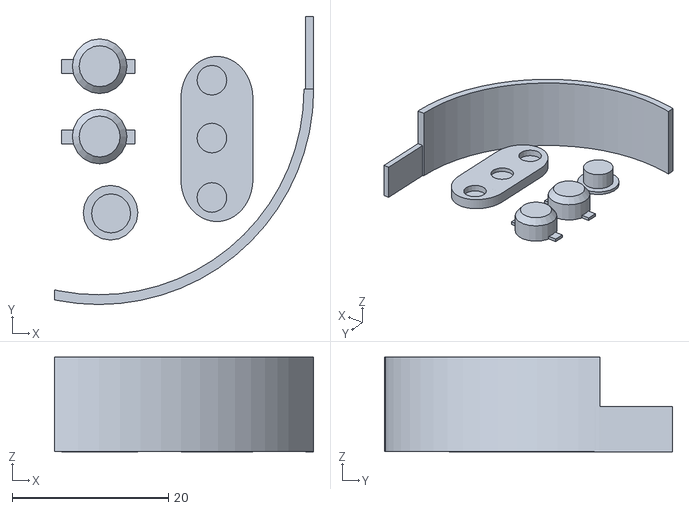
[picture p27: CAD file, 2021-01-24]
Hardware/Controllers/3d printable parts/Left Controller/buttons.stl
33.2 x 36.9 x 12.1

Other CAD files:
Hardware/Controllers/3d printable parts/Left Controller/toppart.stl
Hardware/Controllers/3d printable parts/Right Controller/buttons.stl
Hardware/Controllers/3d printable parts/Left Controller/middlepart.stl
Hardware/Controllers/3d printable parts/Right Controller/bottompart.stl

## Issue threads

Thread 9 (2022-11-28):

"mpu" question

LabrentFiero, 2022-11-28:
Hello. I don't have an mpu9250. Can I use mpu6050 without magnetometer in your project?

LiquidCGS, 2022-12-26:
You can but with the current driver version you'll get yaw drift over time so you'll have to keep recentering your view every now and then, either by pressing f8 or with the controllers if you build them.

I'm working on something to eliminate the need for an IMU wtih a magnetometer but it's still very experimental. I plan to have it out by next driver release.

Closed 2023-01-03.

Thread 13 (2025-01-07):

Conversion possibility?

Caldoric, 2025-01-07:
Hey there! Had a totally weird question I wanted to ask... Do you think this project might be at all useful to convert existing flight stick grips (E.G. the SCG GNX from VKBControllers, or the Constellation ALPHA or ALPHA-Prime from Virpil) into viable VR controllers? They've already got pretty much the right form factor, (minus any sort of grip triggers/sensors,) they've got tons of extra input options (~30+ inputs per hand, which is nice,) and as far as I know, (which admittedly isn't much when it comes to the fields of electronics and programming,) all the "important" hardware is located in the grips themselves, tho there's also a board or two usually located in the "base" that the grips/sticks mount to, and idk how important those are, so this line of thought could be completely hooped from the word "go".

Tbh, part of me was hoping it might be possible to make a sort of "Frankenstein's monster" fusion of the Index Knuckles (using the IR sensor arch, grip-pad, and possibly even the thumb trackpad (tho I wouldn't hold my breath on that one)) with the aforementioned flight stick grips to partially ease the process, tho knowing my luck, it would only make things exponentially harder.

As such, I figured I'd ask someone such as yourself for your more experienced input on the matter.

Anywho, please do correct me if I'm getting overly ambitious with any (or all) of my idea(s) here.

(Links to the stick grips I mentioned, if it turns out they're helpful:)
https://www.vkbcontrollers.com/products/scg-gnx-space-combat-grip-add-on?variant=39779832365174
https://virpil-controls.us.com/vpc-constellation-alpha-l.html
https://virpil-controls.us.com/vpc-constellation-alpha-prime-l.html

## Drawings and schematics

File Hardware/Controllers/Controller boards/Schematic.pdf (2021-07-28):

## BAT 12

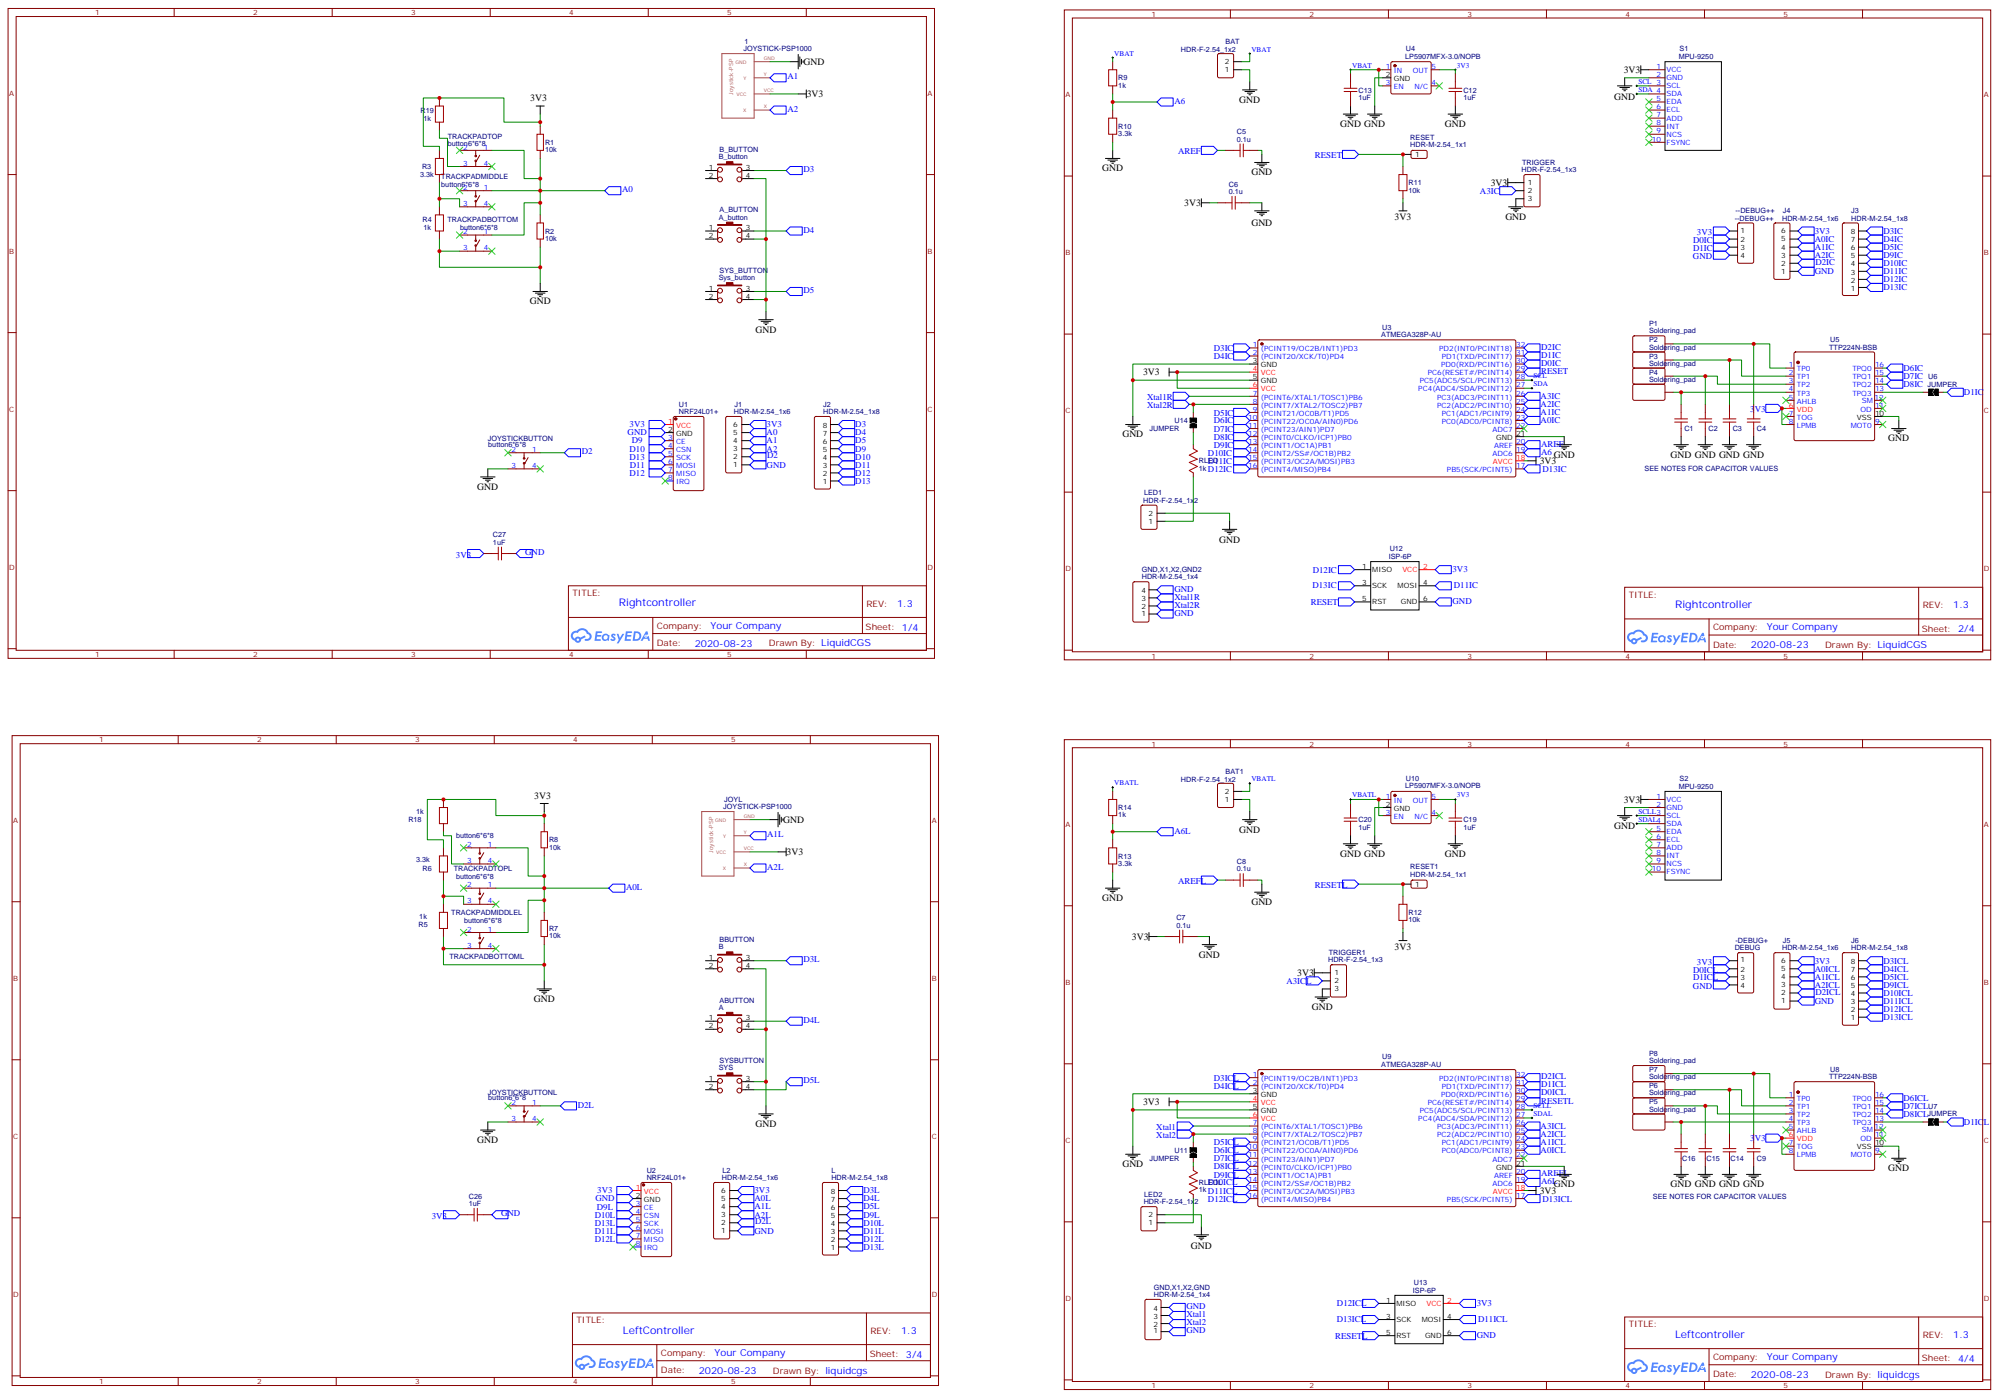
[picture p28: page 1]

GND GND
SEE NOTES FOR CAPACITOR VALUES

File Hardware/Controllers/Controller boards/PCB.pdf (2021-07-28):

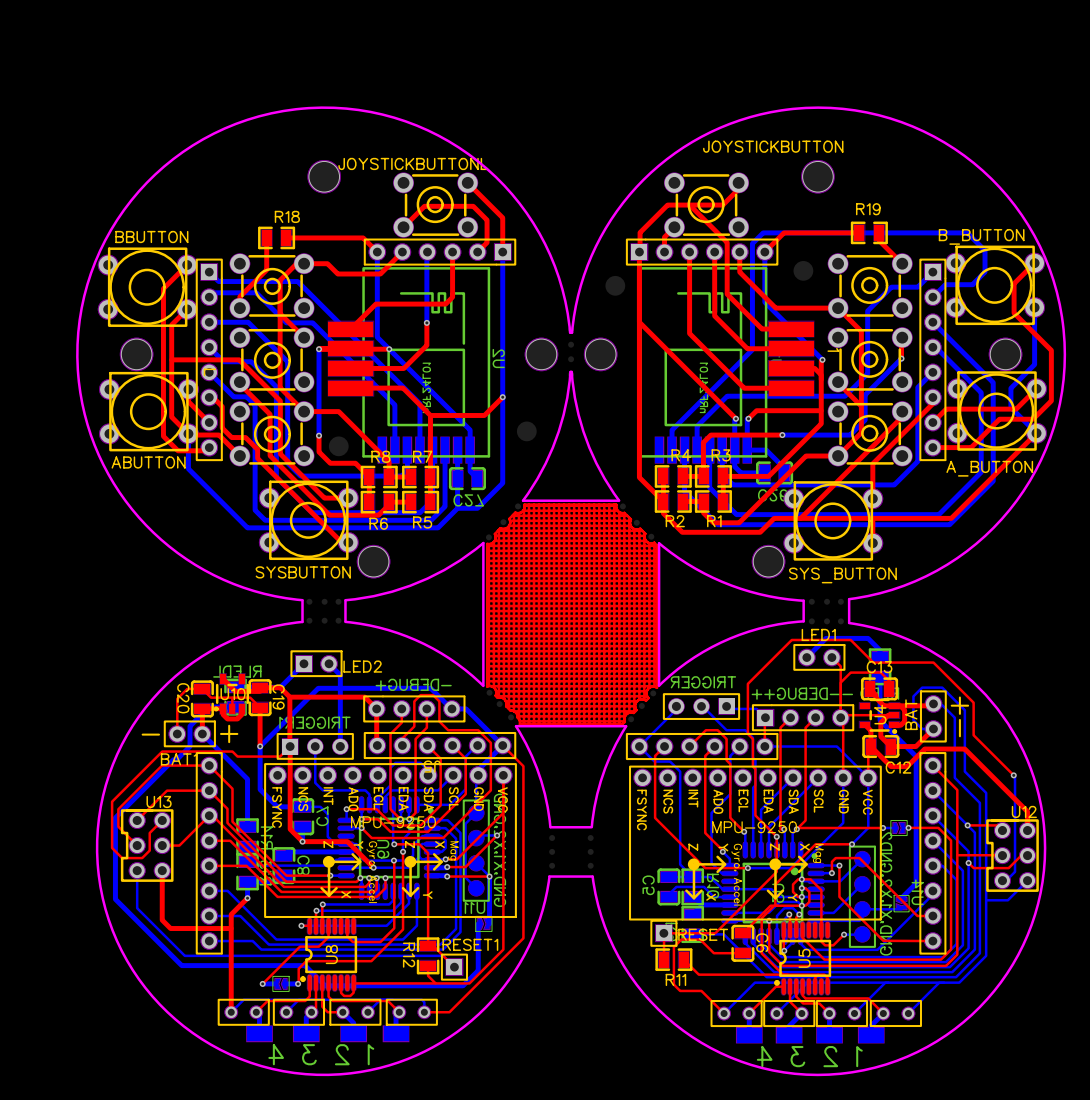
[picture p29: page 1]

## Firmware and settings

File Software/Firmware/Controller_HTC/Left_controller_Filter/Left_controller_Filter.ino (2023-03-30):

/*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
  The above copyright notice and this permission notice shall be included in all copies or substantial portions of the Software.

  THE SOFTWARE IS PROVIDED "AS IS", WITHOUT WARRANTY OF ANY KIND, EXPRESS OR IMPLIED,INCLUDING BUT NOT LIMITED TO
  THE WARRANTIES OF MERCHANTABILITY, FITNESS FOR A PARTICULAR PURPOSE AND NONINFRINGEMENT. IN NO EVENT SHALL THE
  AUTHORS OR COPYRIGHT HOLDERS BE LIABLE FOR ANY CLAIM, DAMAGES OR OTHER LIABILITY, WHETHER IN AN ACTION OF CONTRACT,
  TORT OR OTHERWISE, ARISING FROM, OUT OF OR IN CONNECTION WITH THE SOFTWARE OR THE USE OR OTHER DEALINGS IN THE SOFTWARE.
*/

#include <Wire.h>
#include <SPI.h>
#include <EEPROM.h>
#include "RF24.h"
#include "FastIMU.h"
#include "Madgwick.h"

//==========================================================================================================
//************************************ USER CONFIGURABLE STUFF HERE*****************************************
//==========================================================================================================

//#define SERIAL_DEBUG
#define IMU_ADDRESS     0x68                // You can find it out by using the IMUIdentifier example
MPU9250 IMU;                                // IMU type
#define CALPIN              4               //pin to start mag calibration at power on

#define SysPin              4
#define MenuPin             3
#define GripPin             6
#define JoyXPin             A1
#define JoyYPin             A2
#define JoyClickPin         2
#define TriggerPin          A3
#define VbatPin             A0

#define BatLevelMax         968             //you need to find all of these values on your own
#define JoyXMin             200             //check on the utils folder for sketches and instructions
#define JoyXMax             900             //that help on getting these values
#define JoyYMin             150             //YOU NEED TO DO THIS FOR BOTH CONTROLLERS
#define JoyYMax             870             //if you use these values without changing them you MAY
#define JoyXDeadZoneMin     515             //get stick drift
#define JoyXDeadZoneMax     590
#define JoyYDeadZoneMin     430
#define JoyYDeadZoneMax     560
//==========================================================================================================


calData calib =
{ false,                   //data valid?
  {0, 0, 0},              //Accel bias
  {0, 0, 0},              //Gyro bias
  {0, 0, 0},              //Mag bias
  {1, 1, 1},              //Mag Scale
};

#define HTC_SysClick        0x0001
#define HTC_MenuClick       0x0002
#define HTC_ThumbstickClick 0x0004
#define HTC_GripClick       0x0008
#define HTC_ThumbstickTouch 0x0010
//==========================================================================================================
//************************************* Data packet stuff *************************************************
//==========================================================================================================
struct ctrlData {
  int16_t qW;
  int16_t qX;
  int16_t qY;
  int16_t qZ;
  int16_t accX;
  int16_t accY;
  int16_t accZ;
  uint16_t BTN;
  uint8_t  trigg;
  int8_t  axisX;
  int8_t  axisY;
  int8_t  trackY;
  uint8_t  vBAT;
  uint8_t  fingerThumb;
  uint8_t  fingerIndex;
  uint8_t  fingerMiddle;
  uint8_t  fingerRing;
  uint8_t  fingerPinky;
  uint8_t  gripForce;
  uint16_t Data;
};
ctrlData data;
//==========================================================================================================
//**************************************** Analog inputs ***************************************************
//==========================================================================================================
int tracky;
int trackoutput;
int axisX;
int axisY;
bool joyTouch = false;
//==========================================================================================================
//**************************************** RF Data stuff ***************************************************
//==========================================================================================================
RF24 radio(9, 10);
//uint64_t Pipe = 0xF0F0F0F0E1LL; //right
uint64_t Pipe = 0xF0F0F0F0D2LL; //left
//==========================================================================================================
//**************************************** IMU variables ***************************************************
//==========================================================================================================
AccelData IMUAccel;
GyroData IMUGyro;
MagData IMUMag;
//==========================================================================================================
//************************************** Filter variables **************************************************
//==========================================================================================================
Madgwick filter;
static const float MadgwickBeta = 0.16f;
float rot = 0.f;
//==========================================================================================================

void setup() {
  Wire.begin();
  Wire.setClock(400000); //400khz clock
  pinMode(SysPin, INPUT_PULLUP);
  pinMode(MenuPin, INPUT_PULLUP);
  pinMode(GripPin, INPUT_PULLUP);
  pinMode(JoyClickPin, INPUT_PULLUP);
  pinMode(TriggerPin, INPUT_PULLUP);

#ifdef SERIAL_DEBUG
  Serial.begin(38400);
#endif

  radio.begin();
  radio.setPayloadSize(32);
  radio.setPALevel(RF24_PA_MAX);
  radio.setDataRate(RF24_2MBPS);
  radio.openWritingPipe(Pipe);
  radio.startListening();
  radio.setAutoAck(false);

  int err = IMU.init(calib, IMU_ADDRESS);
  if (err != 0)
  {
    Serial.print("IMU ERROR: ");
    Serial.println(err);
    while (true);
  }
  if (!radio.isChipConnected())
  {
    Serial.println("NRF24L01 Module not detected!");
    while (true);
  }
  else
  {
    Serial.println("NRF24L01 Module up and running!");
  }

  EEPROM.get(210, calib);

  bool calDone = !calib.valid;                             //check if calibration values are on flash
  while (calDone)
  {
    delay(1000);
    Serial.print("Calibration not done!");
    if (!digitalRead(CALPIN))
    {
      calDone = false;
    }
  }
  if (!digitalRead(CALPIN)) {
    if (!digitalRead(MenuPin)) {
      Serial.println("Accelerometer and gyroscope calibration mode.");
      Serial.println("Keep IMU completely still on flat and level surface.");
      delay(8000);
      IMU.calibrateAccelGyro(&calib);
      Serial.println("Accel & Gyro calibration complete!");
      calib.valid = true;
    }
    else {
      if (IMU.hasMagnetometer()) {
        Serial.println("Magnetic calibration mode.");
        Serial.println("Move IMU in figure 8 until done.");
        delay(3000);
        IMU.calibrateMag(&calib);
        Serial.println("Magnetic calibration complete!");
        delay(1000);
      }
    }
    printCalibration();
    Serial.println("Writing values to EEPROM!");
    EEPROM.put(210, calib);
    delay(3000);
  }

  //initialize controller data.
  data.qW = 1;
  data.qX = 0;
  data.qY = 0;
  data.qZ = 0;
  data.BTN = 0;
  data.trigg = 0;
  data.axisX = 0;
  data.axisY = 0;
  data.trackY = 0;
  data.vBAT = 0;
  data.fingerThumb = 0;
  data.fingerIndex = 0;
  data.fingerMiddle = 0;
  data.fingerRing = 0;
  data.fingerPinky = 0;
  data.Data = 0xFF;

  filter.begin(MadgwickBeta);

  err = IMU.init(calib, IMU_ADDRESS);
  if (err != 0)
  {
    Serial.print("IMU ERROR: ");
    Serial.println(err);
    while (true);
  }
}

void loop() {

  IMU.update();
  IMU.getAccel(&IMUAccel);
  IMU.getGyro(&IMUGyro);

  if (IMU.hasMagnetometer()) {
    IMU.getMag(&IMUMag);
    filter.update(IMUGyro.gyroX, IMUGyro.gyroY, IMUGyro.gyroZ, IMUAccel.accelX, IMUAccel.accelY, IMUAccel.accelZ, IMUMag.magX, IMUMag.magY, IMUMag.magZ);
  }
  else {
    filter.updateIMU(IMUGyro.gyroX, IMUGyro.gyroY, IMUGyro.gyroZ, IMUAccel.accelX, IMUAccel.accelY, IMUAccel.accelZ);
  }

  rot += (abs(IMUGyro.gyroX) + abs(IMUGyro.gyroY) + abs(IMUGyro.gyroZ));
  if (rot > 64000.f) rot = 64000.f;
  rot *= 0.97f;
  filter.changeBeta(rot * (1.5 - 0.1) / 64000 + 0.1);

  int btn = 0;

  axisX = analogRead(JoyXPin);
  axisY = analogRead(JoyYPin);

  if (axisX > JoyXDeadZoneMax || axisX < JoyXDeadZoneMin) {
    data.axisX = -map(axisX, JoyXMin, JoyXMax, -127, 127);
  } else {
    data.axisX = 0;
  }

  if (axisY > JoyYDeadZoneMax || axisY < JoyYDeadZoneMin) {
    data.axisY = map(axisY, JoyYMin, JoyYMax, -127, 127);
    btn |= HTC_ThumbstickTouch;
  } else {
    data.axisY = 0;
  }

  data.trigg = (map(analogRead(TriggerPin), 1024, 0, 0, 255));

  if (!digitalRead(SysPin)) {
    btn |= HTC_SysClick;
  }
  if (!digitalRead(MenuPin)) {
    btn |= HTC_MenuClick;
  }
  if (!digitalRead(JoyClickPin)) {
    btn |= HTC_ThumbstickClick;
  }
  if (digitalRead(GripPin)) {
    btn |= HTC_GripClick;
  }


  data.BTN = btn;
  data.trackY = (trackoutput * 127);
  data.vBAT = (map(analogRead(VbatPin), 787, BatLevelMax, 0, 255));
  data.qW = (int16_t)(filter.getQuatW() * 32767.f);
  data.qX = (int16_t)(filter.getQuatY() * 32767.f);
  data.qY = (int16_t)(filter.getQuatZ() * 32767.f);
  data.qZ = (int16_t)(filter.getQuatX() * 32767.f);
  data.accX = (short)(IMUAccel.accelX * 2048);
  data.accY = (short)(IMUAccel.accelY * 2048);
  data.accZ = (short)(IMUAccel.accelZ * 2048);

  radio.stopListening();
  radio.write(&data, sizeof(ctrlData));
  radio.startListening();
}
void printCalibration()
{
  Serial.println("Accel biases X/Y/Z: ");
  Serial.print(calib.accelBias[0]);
  Serial.print(", ");
  Serial.print(calib.accelBias[1]);
  Serial.print(", ");
  Serial.println(calib.accelBias[2]);
  Serial.println("Gyro biases X/Y/Z: ");
  Serial.print(calib.gyroBias[0]);
  Serial.print(", ");
  Serial.print(calib.gyroBias[1]);
  Serial.print(", ");
  Serial.println(calib.gyroBias[2]);
  if (IMU.hasMagnetometer()) {
    Serial.println("Mag biases X/Y/Z: ");
    Serial.print(calib.magBias[0]);
    Serial.print(", ");
    Serial.print(calib.magBias[1]);
    Serial.print(", ");
    Serial.println(calib.magBias[2]);
    Serial.println("Mag Scale X/Y/Z: ");
    Serial.print(calib.magScale[0]);
    Serial.print(", ");
    Serial.print(calib.magScale[1]);
    Serial.print(", ");
    Serial.println(calib.magScale[2]);
  }
  delay(5000);
}

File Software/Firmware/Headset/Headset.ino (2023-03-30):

/*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
  The above copyright notice and this permission notice shall be included in all copies or substantial portions of the Software.

  THE SOFTWARE IS PROVIDED "AS IS", WITHOUT WARRANTY OF ANY KIND, EXPRESS OR IMPLIED,INCLUDING BUT NOT LIMITED TO
  THE WARRANTIES OF MERCHANTABILITY, FITNESS FOR A PARTICULAR PURPOSE AND NONINFRINGEMENT. IN NO EVENT SHALL THE
  AUTHORS OR COPYRIGHT HOLDERS BE LIABLE FOR ANY CLAIM, DAMAGES OR OTHER LIABILITY, WHETHER IN AN ACTION OF CONTRACT,
  TORT OR OTHERWISE, ARISING FROM, OUT OF OR IN CONNECTION WITH THE SOFTWARE OR THE USE OR OTHER DEALINGS IN THE SOFTWARE.
*/

#include <Wire.h>
#include <SPI.h>
#include "RF24.h"
#include "FastIMU.h"

//==========================================================================================================
//************************************ USER CONFIGURABLE STUFF HERE*****************************************
//==========================================================================================================

#define IMU_ADDRESS     0x69                // You can find it out by using the IMUIdentifier example
BMI055 IMU;                                 // IMU type
#define CALPIN              4               // Pin to start mag calibration at power on.
#define EEPROM_CAL                          // Comment this if your MCU doesn't support EEPROM.
//#define USE_RF                            // Comment this to disalbe RF functionality.
//#define SERIAL_DEBUG                        // Uncomment this to make the serial port spicy.

#define TRANSPORT_TYPE             1        //1 = HID (default), 2 = UART
#define TRANSPORT_SERIAL_PORT      Serial   // Must_not be same as SERIAL_DEBUG (if that is enabled)
#define TRANSPORT_SERIAL_BAUDRATE  230400

//==========================================================================================================
//************************************* Calibration stuff *************************************************
//==========================================================================================================
//eeprom-less mcu stuff, you don't need to touch these if you do the eeprom calibration
calData calib =
{ true,                   //data valid?
  {0, 0, 0},              //Accel bias
  {0, 0, 0},              //Gyro bias
  {0, 0, 0},              //Mag bias
  {1, 1, 1},              //Mag Scale
};
#ifdef EEPROM_CAL
#include <EEPROM.h>
#endif
//==========================================================================================================
//************************************ DATA TRANSPORT LAYER ************************************************
//==========================================================================================================

class DataTransport {
  public:
    virtual ~DataTransport() {}
    virtual void setup() = 0;
    virtual void sendPacket(const void* packet, int len);
};

#if TRANSPORT_TYPE == 1

#include "HID.h"

static const uint8_t USB_HID_Descriptor[] PROGMEM = {

  0x06, 0x03, 0x00,   // USAGE_PAGE (vendor defined)
  0x09, 0x00,         // USAGE (Undefined)
  0xa1, 0x01,         // COLLECTION (Application)
  0x15, 0x00,         //   LOGICAL_MINIMUM (0)
  0x26, 0xff, 0x00,   //   LOGICAL_MAXIMUM (255)
  0x85, 0x01,         //   REPORT_ID (1)
  0x75, 0x08,         //   REPORT_SIZE (16)

  0x95, 0x3f,         //   REPORT_COUNT (1)

  0x09, 0x00,         //   USAGE (Undefined)
  0x81, 0x02,         //   INPUT (Data,Var,Abs) - to the host
  0xc0
};

class HIDTransport : public DataTransport {
  public:
    void setup()
    {
      static HIDSubDescriptor node(USB_HID_Descriptor, sizeof(USB_HID_Descriptor));
      HID().AppendDescriptor(&node);
    }

    void sendPacket(const void* packet, int len)
    {
      HID().SendReport(1, packet, len);
    }
};

#define TransportClass HIDTransport

#elif TRANSPORT_TYPE == 2

#define UART_MAGIC ((uint8_t)0xAA)

class UARTTransport : public DataTransport {
  public:
    UARTTransport() : port(TRANSPORT_SERIAL_PORT) {}

    void setup()
    {
      port.begin(TRANSPORT_SERIAL_BAUDRATE);
      cnt = 0;
    }

    void sendPacket(const void* packet, int len)
    {
      // TODO: Check len < 256
      const uint8_t dataLen = (uint8_t)len;

      // We simply send <magic:1><length:1><data:length> where magic=0xAA, length=len and data=packet
      // Adding a CRC might be a good idea later
      port.write((uint8_t)UART_MAGIC);
      port.write(cnt++);
      port.write(dataLen + 1);
      port.write((uint8_t)0x01); // Dummy report number (not really used)
      port.write((const uint8_t*)packet, dataLen);
    }

  private:
    uint8_t cnt;
    HardwareSerial& port;
};

#define TransportClass UARTTransport

#else
#error "unsupported transport type: "
#endif

static TransportClass transport;

//==========================================================================================================
//************************************* Data packet stuff *************************************************
//==========================================================================================================
struct HMDRAWPacket
{
  uint8_t  PacketID;

  int16_t AccX;
  int16_t AccY;
  int16_t AccZ;

  int16_t GyroX;
  int16_t GyroY;
  int16_t GyroZ;

  int16_t MagX;
  int16_t MagY;
  int16_t MagZ;

  uint16_t HMDData;

  uint8_t Padding[30];

};
struct ControllerPacket
{
  uint8_t PacketID;
  int16_t Ctrl1_QuatW;
  int16_t Ctrl1_QuatX;
  int16_t Ctrl1_QuatY;
  int16_t Ctrl1_QuatZ;
  int16_t Ctrl1_AccelX;
  int16_t Ctrl1_AccelY;
  int16_t Ctrl1_AccelZ;
  uint16_t Ctrl1_Buttons;
  uint8_t Ctrl1_Trigger;
  int8_t Ctrl1_axisX;
  int8_t Ctrl1_axisY;
  int8_t Ctrl1_trackY;
  uint8_t Ctrl1_vBat;
  uint8_t Ctrl1_THUMB;
  uint8_t Ctrl1_INDEX;
  uint8_t Ctrl1_MIDDLE;
  uint8_t Ctrl1_RING;
  uint8_t Ctrl1_PINKY;
  uint8_t Ctrl1_AnalogGrip;
  uint16_t Ctrl1_Data;

  int16_t Ctrl2_QuatW;
  int16_t Ctrl2_QuatX;
  int16_t Ctrl2_QuatY;
  int16_t Ctrl2_QuatZ;
  int16_t Ctrl2_AccelX;
  int16_t Ctrl2_AccelY;
  int16_t Ctrl2_AccelZ;
  uint16_t Ctrl2_Buttons;
  uint8_t Ctrl2_Trigger;
  int8_t Ctrl2_axisX;
  int8_t Ctrl2_axisY;
  int8_t Ctrl2_trackY;
  uint8_t Ctrl2_vBat;
  uint8_t Ctrl2_THUMB;
  uint8_t Ctrl2_INDEX;
  uint8_t Ctrl2_MIDDLE;
  uint8_t Ctrl2_RING;
  uint8_t Ctrl2_PINKY;
  uint8_t Ctrl2_AnalogGrip;
  uint16_t Ctrl2_Data;
};

static HMDRAWPacket HMDRawData;
static ControllerPacket ContData;
//==========================================================================================================
//**************************************** RF Data stuff ***************************************************
//==========================================================================================================
#ifdef USE_RF
const uint64_t rightCtrlPipe = 0xF0F0F0F0E1LL;
const uint64_t leftCtrlPipe = 0xF0F0F0F0D2LL;
const uint64_t trackerPipe = 0xF0F0F0F0C3LL;

RF24 radio(9, 10); // CE, CSN on Blue Pill
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

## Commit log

2021-01-24 Added Controller boards readme.md
2021-01-24 Fixed the markdown on controller boards?
2021-01-24 Updated gerber file and added boards link
2021-01-24 Update driver_main.cpp
    no longer tovr bridge
    [driver_main.cpp]
2021-01-24 renamed Guide to docs, added a picture to the readme.md
    [Component list.xlsx]
2021-01-26 Update driver_main.cpp
    Added x axis offset, fixed y axis offset
    [driver_main.cpp]
2021-03-07 Added displays/schematics/etc
2021-03-07 Added Driver.md to the docs
2021-03-08 Firmware update: fixed 32 byte rf24 tx limit
    [Headset.ino, Left_controller.ino]
2021-03-08 Split controller props to a different file
2021-03-09 Added battery % tracking
2021-03-15 Updated Receiver schematic
2021-03-20 Tracker velocity
2021-03-31 Fixed PSMS Connection error state
    [dataHandler.h]
2021-04-01 fixed index finger tracking
    I broke finger tracking somewhere now its fixed
2021-04-02 Bone based finger tracking
2021-04-03 Fixed hand tracking stuff
    basically I'm an idiot
    [driver_main.cpp]
2021-04-03 Fixed finger tracking stuff
    LucidVR's open vr gloves finger tracking code, check them out here https://github.com/LucidVR/opengloves-driver
2021-04-04 Velocity fix
    Thanks okawo!
    [driver_main.cpp]
2021-04-04 Velocity fixes
2021-04-22 No longer dangerous for epileptic people
    [dataHandler.h]
2021-04-22 Updated finger tracking stuff to new controller data structure
2021-04-22 Updated finger tracking to work with new data structure
2021-05-05 Added MIT notice.
    Added MIT license stuff for LucidVR's finger tracking code.
2021-05-05 Controller and HMD yaw pitch and roll offsets.
2021-05-05 Forgot to reset newContData
    Thanks KnuckleDF!
    [Headset.ino]
2021-05-05 Updated Driver doc with new configuration stuff
2021-05-05 Arduino DUE notice.
2021-05-06 Created calibration sketch.
2021-05-06 Magnetometer corrected headset code update.
    [Calibration.ino, Headset.ino]
2021-05-07 Moved mag corrected headset to experimental testing.
    [Calibration.ino, Headset.ino]
2021-05-17 Mag calibrated controller using DMP
2021-05-17 STM32 madgwick tests
2021-05-17 Updated Controller code to eliminate drift
    Now using mag correction code.
    [Left_controller.ino]
2021-05-19 allow for storing of calibration data
2021-05-19 mag corrected headset code
    [Calibration.ino, Headset.ino]
2021-07-27 Start calibration with the sys button on power up
2021-07-28 updated pcb design changes in desc
    Buttons have the wrong pins assigned to them in schematic view so those are wrong.
    AVRs are stupid and need a crystal to flash the bootloader so added pads for a temporary 8/12/16mhz crystal to burn the bootloader.
2021-08-04 updated firmware to work with driver version 1.23
2021-08-04 Updated headset code to work with driver version 1.23
2021-08-13 Added device metadata
2021-08-16 Added filter
2021-08-16 change scale of sensor components
2021-08-16 include the filter
2021-08-17 Starting the filter fast to minimize stabilization time
2021-08-17 Settings entry for filter beta
2021-08-31 Updated driver config doc
2021-10-19 Fixed some deltatime stuff
    [driver_main.cpp]
2021-10-19 Accelerometer interpolation code
2021-10-20 HMD accelerometer based positioning stuff
2022-01-08 Controller accelerometer data handling is now less broken.
    this was fucked
2022-01-23 Controller accel tests that don't work.
    it didn't work
    [dataHandler.h]
2022-01-23 Accelerometer stuff for controllers
2022-07-03 Removed old janky filter and replaced with Kalman filter
    [dataHandler.h]
2022-07-03 Poll PSMS at 2x camera refresh rate.
2022-08-01 IMU Linear velocity calculations
2022-08-17 IMU and Camera update with different parameters
2022-08-20 Handle rotation of accelerometer vector
2022-08-20 Separate IMU gain, again
2022-08-20 only update camera on new frame
2022-08-21 Cleanup and using proper velocity calculations.
2022-09-13 Fix filter
2022-09-13 Fix distortion (thanks Anranarl!)
    [driver_main.cpp]
2022-09-16 Separate filter parameters for HMD and controllers
2022-10-02 Angular velocity and fallback 3dof reporting.
2022-10-03 Dynamic hmd filter beta.
2022-10-04 velocity tweaks
2022-10-04 fix dynamic filter.
2022-10-07 avoid wrong velocity on new real tracking point
    [dataHandler.h]
2022-10-07 Update controller filters
2022-10-11 Fix viewport zoom bug
    [driver_main.cpp]
2022-10-11 changed viewport implementation
    removed "DistanceBetweenEyes"
    added "DistanceBetweenLenses" "DistanceBetweenViews" "DisplayWidth" "IsSinglePanel"
    "DistanceBetweenLenses" is the physical distance between the center of the two lenses Unit: m
    "DistanceBetweenViews" is the distance between the center of the two viewports Unit: m
    "DisplayWidth" is the physical width of the display
    "IsSinglePanel" true for single panel and false for dual panel
    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
2022-10-13 BUG fixes
    BUG fixes
    [driver_main.cpp]
2022-11-02 Don't use accelerometer position when not connected to PSMS
2022-11-04 Add support for HMDs connected via UART in driver
2022-11-04 Add UART transport support to HMD
    This commit only covers the non-DMP version of the HMD.
2022-12-14 Rename HID thread to Transport thread
2022-12-26 fix velocity not being reset when psms offline
2022-12-29 Error handling for bad velocity
2022-12-31 Optical drift correction magic
    works like crap only half the time
    also included: some cleanup, settings file updates.
    [dataHandler.h]
2023-01-13 Reinitialize IMU with calibration values
2023-01-13 Add simple kalman filter
2023-01-14 Optical drift correction magic
    [dataHandler.h]
2023-07-28 Unity OpenXR no movement prop fix
    [driver_main.cpp]
2023-08-01 Fix icon and add eye relief meters setting.
    [driver_main.cpp]
2025-09-05 Fix display eye to head rotation
    [driver_main.cpp]

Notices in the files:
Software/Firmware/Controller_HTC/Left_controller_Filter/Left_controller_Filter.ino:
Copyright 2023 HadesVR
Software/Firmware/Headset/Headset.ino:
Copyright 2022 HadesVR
